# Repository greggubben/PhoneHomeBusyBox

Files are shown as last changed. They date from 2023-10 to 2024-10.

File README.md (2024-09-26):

# Phone Home Busy Box

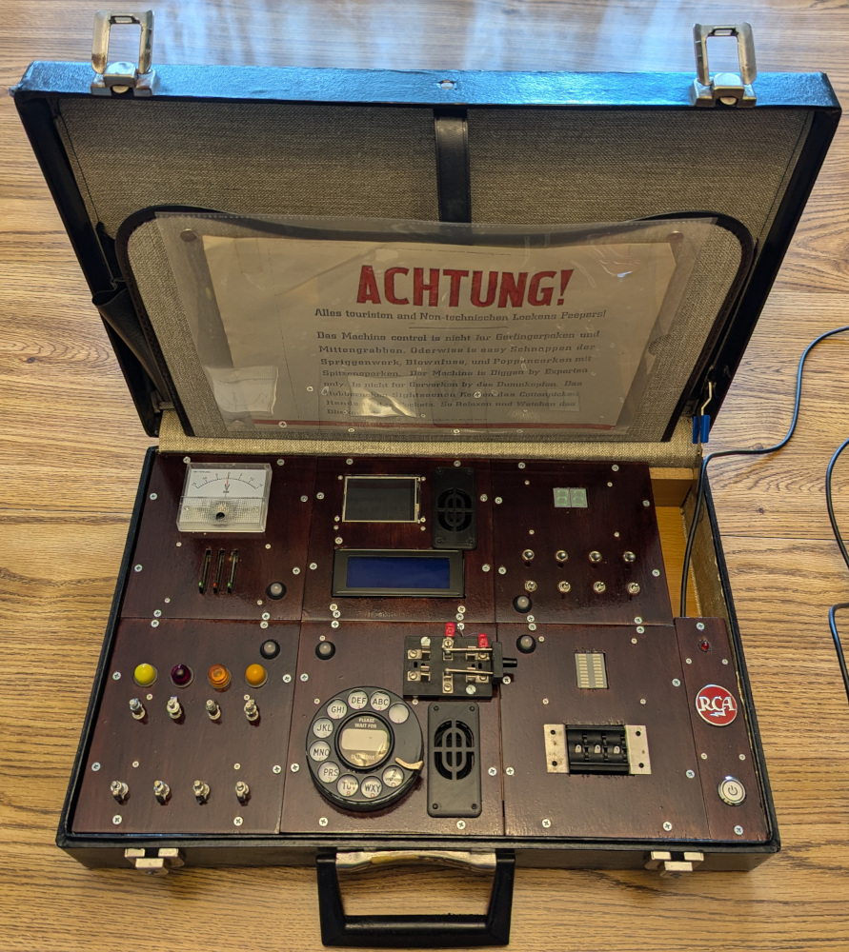
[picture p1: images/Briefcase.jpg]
Picture of the Phone Home Busy Box Briefcase


Picture of the completed Phone Home Busy Box Briefcase.

## Overview

Growing up half of my basement was an electronics lab filled with all sorts of electronic parts. My dad worked for RCA and through RCA supllied many radios to NASA, specifically the Apollo missions. When he passed, I inherited all different kinds of electronic components.

The project started, as most of my projects do, with the question:  What can I do with all these parts?  What became the Phone Home Busy Box Briefcase was inspired by a busy box my dad created for us kids. It had a group of lights and switches along with a rotary phone dialer. As you flipped switches and dialed the phone, the lights would change.

The project started as a bunch of boxes with parts.

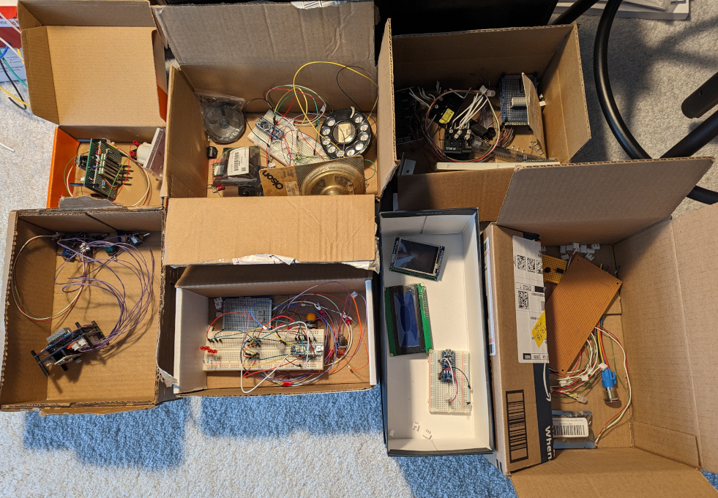
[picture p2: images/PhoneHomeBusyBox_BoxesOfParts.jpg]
Picture of the parts organized into boxes


This git repository is a collection of repositories for a Busy Box placed into a briefcase. The purpose of the Busy Box is to determine a phone number by solving 4 puzzles. This phone number must be dialed in the 5<sup>th</sup> puzzle before time runs out.

There are 6 repositories for 6 of the modules. The 7<sup>th</sup> module is the power module and does not require any code.

- [**Control Module**](Controller) handles the flow of the game.
- [**Slide into Home**](Slider) puzzle is where sliders are moved to reveal the number on the analog meter.
- [**Hook Me Up**](HookMeUp) puzzle has the player connect wires between the top(Brown) and bottom(White) terminals to turn lights on if off or off if on revealing a binary number that must be converted to a base ten number.
- [**Flip the Bits**](FlipBits) puzzle uses switches to reveal a hexidecimal number that must be converted to a base ten number.
- [**Spin Digit**](SpinDigit) puzzle has the player make all the bars go out by spinning the number wheels to reveal the number.
- [**Dialer**](DialerPuzzle) puzzle is where the number must be dialed correctly in order to phone home.

Supporting
- [**Phone Home Library**](PhoneHomeLib) is the common code and definitions used by all modules.
- [**Power Module**](Power) delivers the power to all the modules and creates the PJON data bus for all the modules to communnicate.

## Layout

The Phone Home Busy Box Briefcase layout looks like this:

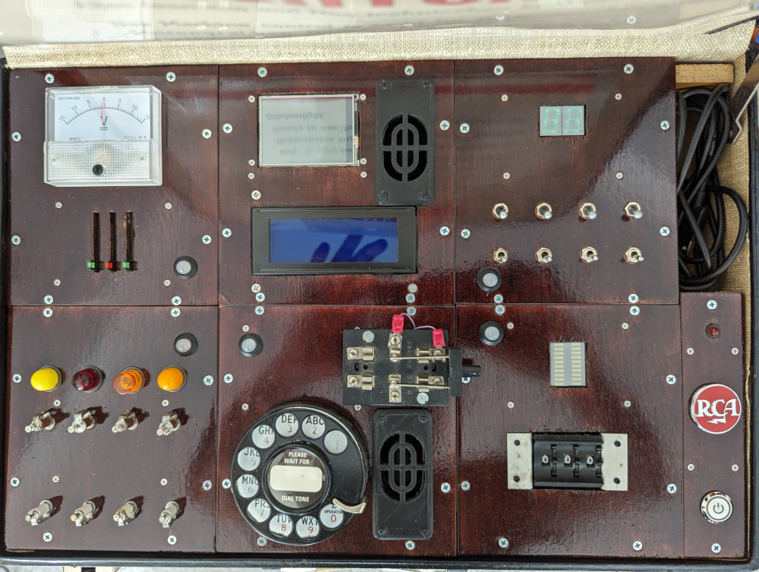
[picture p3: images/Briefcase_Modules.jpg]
Picture of the Phone Home Busy Box Briefcase with all the Modules installed


| Col<br>\\<br>Row | 1 | 2 | 3 | |
| :---: | :---: | :---: | :---: | :---: |
| 1 | **Slide into Home** | **Control Module** | **Flip the Bits** | Cable |
| 2 | **Hook me Up** | **Dialer** | **Spin Digit** | Power |

## Architecture

Each module uses a single Arduino Nano to handle its part of the puzzle. Each of the 5 puzzle modules are capable of running individually with commands being sent through the USB Serial Monitor. When playing the full game, the **Control Module** sends the same commands to each of the puzzle modules in order.

Communication happens using the [PJON \(Padded Jitterning Operative Network\)](https://github.com/gioblu/PJON) protocol over a single wire using [SoftwareBitBang](https://github.com/gioblu/PJON/tree/master/src/strategies/SoftwareBitBang). A common library, [PhoneHomeLib](PhoneHomeLib), is used to establish a common communication language between the **Control Module** and the puzzle modules.
For more details on the common architecture see the [Readme](PhoneHomeLib) in the [PhoneHomeLib](PhoneHomeLib).

## Game Play

When the briefcase is powered up, the **Control Module** pings each puzzle module to confirm it is present. Each puzzle confirms it is functioning and lets the **Control Module** know it is ready to play. The **Control Module** will then ask the player to select the level of difficulty. The TFT Touchscreen will display choice and accept touch inputs. The 4 line LCD screen will display instructions. While the game is being played the Touchscreen will display a clock be displayed showing the time remaining.

| Difficulty | Phone<br>Number | Puzzles | Behavior |
| :---: | --- | --- | --- |
| Easy | Only one | Played in Order | Used to learn the game.<br>Puzzles reveal the phone number to dial. |
| Medium | Selected from several<br>at Random | Played in<br>Random Order | Puzzles reveal the phone number to dial. |
| Hard | Selected from several<br>at Random<br>Number is in<br>Random Order | Played in<br>Random Order | Puzzles reveals random numbers<br>which must be put in the correct order<br>for the phone number to dial. |

The **Control Module** will select a phone number based on the difficulty selected. In the case of a Hard difficulty the numbers will also be randomized. Then the **Control Module** will request playing the 4 number determining puzzles (**Slide into Home**, **Hook me Up**, **Flip the Bits**, **Spin Digit**) in sequential or random order based on the difficulty. Once the 4 puzzles are solved, the **Control Module** will request playing the **Dialer** puzzle for the player to dial the correct phone number based on the results of the solved puzzles.

Colors on the puzzle indicate the state of the puzzle:

| Status<br>Color<br>LED | State | Meaning |
| :---: | :---: | --- |
| Purple | Startup | The puzzle has been powered up and is waiting for a Wakeup message. |
| Blue | Ready | The puzzle is awake and waiting for its turn to start playing. |
| Red | Initialize | The puzzle needs the Player's help initialize the puzzle for playing. |
| Yellow | Playing | The Player is playing the puzzle. |
| Green | Done | The puzzle has been solved. |

When the **Control Module** requests a puzzle to start playing, it also sends the digits the puzzle is expected to use as the solution.

If the puzzle needs the Player to Initialize the puzzle (reset the puzzle) the status LED will turn Red and Initialization instructions will be dislayed on the Control Module's LCD screen. If the puzzle is already initialized or the Player has performed the Initialization tasks, the status LED will turn Yellow and playing instructions will be displayed on the Control Module's LCD screen.

During play the with Player will attempt to solve the puzzle using the instructions provided on the LCD screen. Meanwhile the clock on the Touchscreen will continue to count down. Once the puzzle has been solved, the clock will pause and instructions on how to interpret the number will be displayed on the Touchscreen. Once the Player has determined the number, they can press Next on the Touchscreen to continue to the next puzzle and the count down will continue.

When all 4 number determining puzzles(**Slide into Home**, **Hook me Up**, **Flip the Bits**, **Spin Digit**) have been solved, the **Control Module** will start play on the **Dialer** puzzle for the Player to dial the right phone number to call home.

Upon dialing the correct phone number the count down will stop, a message saying the Player has won, and a tune will play.

## Attribution

I would like to thank [Playful Technology](https://www.youtube.com/@PlayfulTechnology) on YouTube for [introducing me to PJON as a cross module communication tool](https://www.youtube.com/watch?v=u8giZveqlxs&list=PLogiUurtMYtSxku2Itst0msCv8MC2w14P&index=1).

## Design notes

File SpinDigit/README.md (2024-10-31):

# Spin Digit

This puzzle reveals 3 digits. 

## Overview

This puzzle uses 3 rotary switches and 2 10-segment LED Bar Graph displays. The 3 rotary switches represent each of the 3 digits. As each rotary switch is turned it changes the number of LEDs lit on the 2 10-segment LED Bar Graph display. The goal is to make all the bars disappear as in nothing is lit up on the 2 10 bar LED didplays.
When solved, the number on the 3 rotary switched is the number to use.

The 10-segment LED Bar Graph display and LM3914 are throwbacks to the 70s when CBs were all the rage. We had a slide in plate installed in the cars that would accept the CB and connect it up to power and the antenna in the trunk. My Dad's Maverik had battery issues so he created an LED bar display using a LM3914 to show battery voltage and mounted it to a spare CB mount so it could be inserted into his car. The LM3914 is one of his spares, but the 10-segment LED Bar Graph is new. I do not know where the Number Dials came from, but I suspect it was used to dial in a frequency on some device.

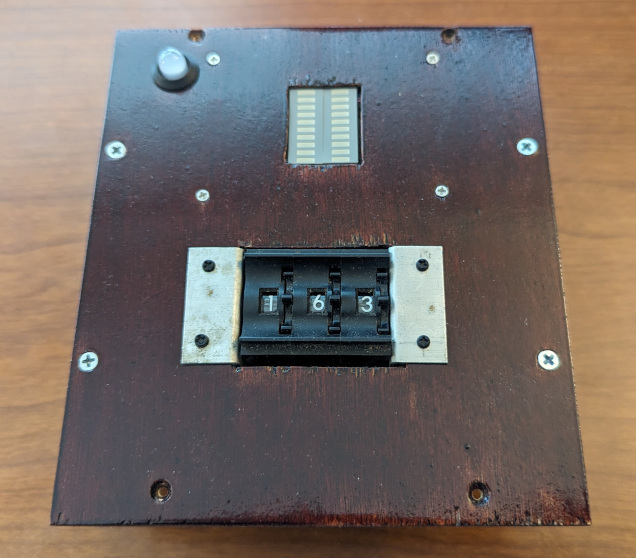
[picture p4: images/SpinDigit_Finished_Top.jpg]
Picture of finished Spin Digit module


## Hardware

The puzzle uses an Arduino Nano as the processor and 2 digital pins drive each of the LED Bar Graph displays through PWM. A MCP23O17 reads the binary value from the 3 rotary switches and is connected to the Arduino Nano via I2C.

The Arduino Nano manages the state of the puzzle which is reflected in the [8mm NeoPixel](https://www.adafruit.com/product/1734) LED from Adafruit. See the [PhoneHome_PuzzleState.h](../PhoneHomeLib/PhoneHome_PuzzleState.h) for states and colors. The [PhoneHome_Definitions.h](../PhoneHomeLib/PhoneHome_Definitions.h) file contains the standard pins used by all Arduino Nanos.

I cannot find the datasheet for the exact model of the Digitran 7-R-108 B rotary switches I used, but it is similar to one of these [Digital Display Data Sheets](https://www.digitran-switches.com/resources). The rotary switches used both binary and digital pins connectioned through the switch to a common source. I used the binary connections to decode the number dialed according to [Table 16 on the Truth Table]( https://www.digitran-switches.com/sites/digitran-switches/files/truthtables.pdf). The common is connected to ground so each of the 4 binary connected are expected to be pulled high.

The [MCP23O17](https://www.adafruit.com/product/732) is a 16 bit I/O Expander connected to the Arduino Nano using I2C. GPA0-GPA3 is connected to the right switch, GPA4-GPA7 is connected to the middle switch, and GPB0-GPB3 is connected to the left switch. This allows a full 16-bit read to return the complete value of the rotary switches. All 16 pins are initialized to use the builtin pull-up resistor. The I2C connection to the MCP23O17's SCK(12) and SDA(13) is made using the default I2C pins on the Arduino Nano. Pins A0(15), A1(16), and A2(17) on the MCP23O17 are connected to ground to use the default I2C address of 0x20. The RESET(18) pin on the MCP23O17 is connected to +5v. I had left these 4 pins floating with wildly unpredictable results. :-)

The [LM3914 Bar Display Driver](https://www.ti.com/lit/ds/symlink/lm3914.pdf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) is used to drive a [10-Segment LED Bar Graph Display](https://www.amazon.com/dp/B07BJ8ZGP7). Pins 1 , 18, 17, 16 & 15(aka LED No 1-5) of the LM3914 are connected to the Green LEDs, pins 14, 13 & 12(aka LED No 6-8) are connected to the Yellow LEDs, and pins 11 & 10(aka LED No 9-10) are connected the end LEDs.
On the LM3914, a 1.1K ohm resistor is placed between pin 8 (Ref Adj) and Ground. A 2.4K Ohm resistor is placed between pin 8 (Ref Adj) and pins 6 & 7 (RHI & Ref Out) since pins 6 & 7 are connected. Pin 9 on the LM3914 sets the Mode of the display and is connected to +5V indicating Bar Graph Mode. Pin 4 (RLO) is connected to Ground.
When I connected the Arduino pin 5 & 6 to pin 5 (Signal Source) on the LM3914, the display flashed with the PWM. I had to add a Low Pass Filter using a 4.7uF Capacitor and a 12K ohm resistor so that the PWM pulses would be leveled out for the LM3914. It turns out the LM3914 is very responsive so without the Low Pass Filter the LED Bar Graph was flashing all on to all off.

The following is a Fritzing diagram of the connections.

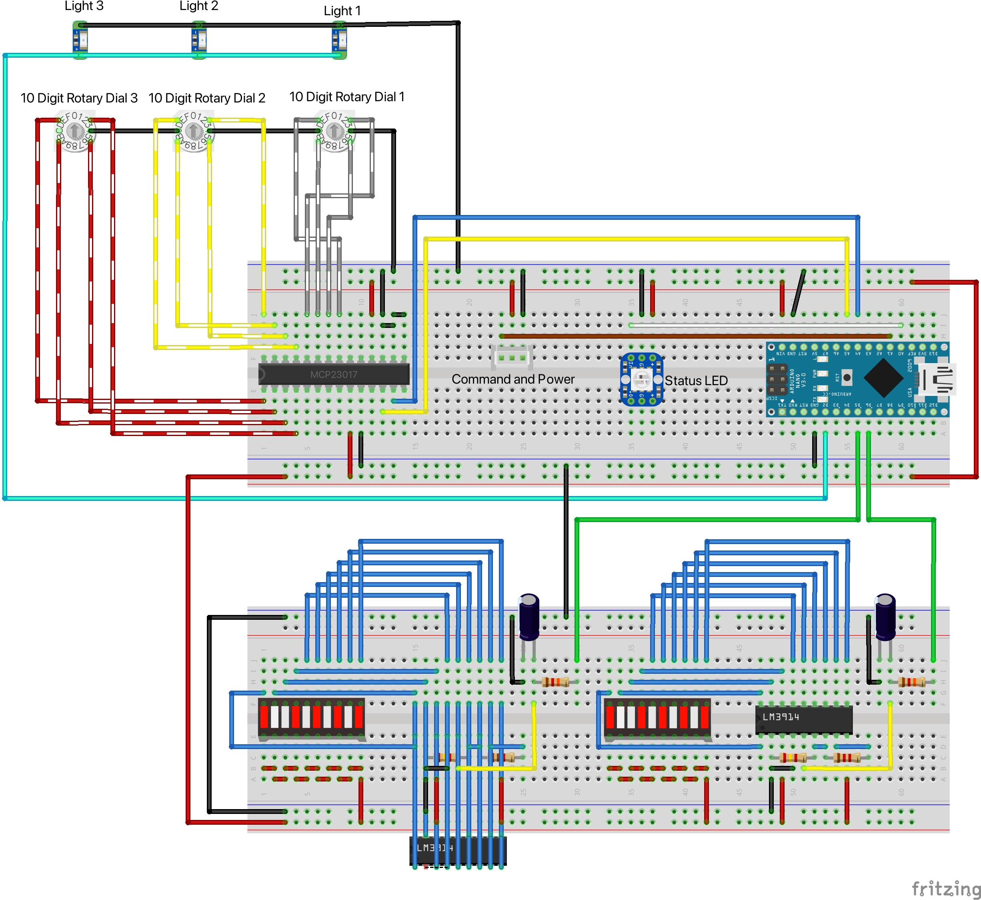
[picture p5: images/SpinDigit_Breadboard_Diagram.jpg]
Breadboard Diagram


I only wired up one of the LM3914 and LED Bar Graphs pairs on the breadboard.

The Spin Digit puzzle is soldered on 2 5cmx7cm 2.54mm double sided prototype PCB circuit board sandwiched together using headers to pass data. The Arduino Nano is placed on one of the boards using headers. The connection to the bus is made at the top of the Arduino Nano using a 3 pin JST connector. The neopixel state indicator LED is connected using a 3 pin JST connector as well. The 8 switches are connected to this board using 2 pin JST connectors.

The MCP23O17 is soldered to the same board as the Arduino using sockets. There are 3 4-pin JST connectors are attached to the IO pins on the MCP23017 as well. These are color coded to ensure the correct rotary dial is connected to the right bank of IO pins.

The LM3914s and LED Bar Graph Displays are placed on sockets soldered onto a second prototype PCB circuit boardi. Headers connect the 2 boards to pass +5v, Ground, and the 2 PWM signal lines for each display. The Low Pass Filters for each side are also soldered onto this board.

Soldered Spin Digit from the top<br>
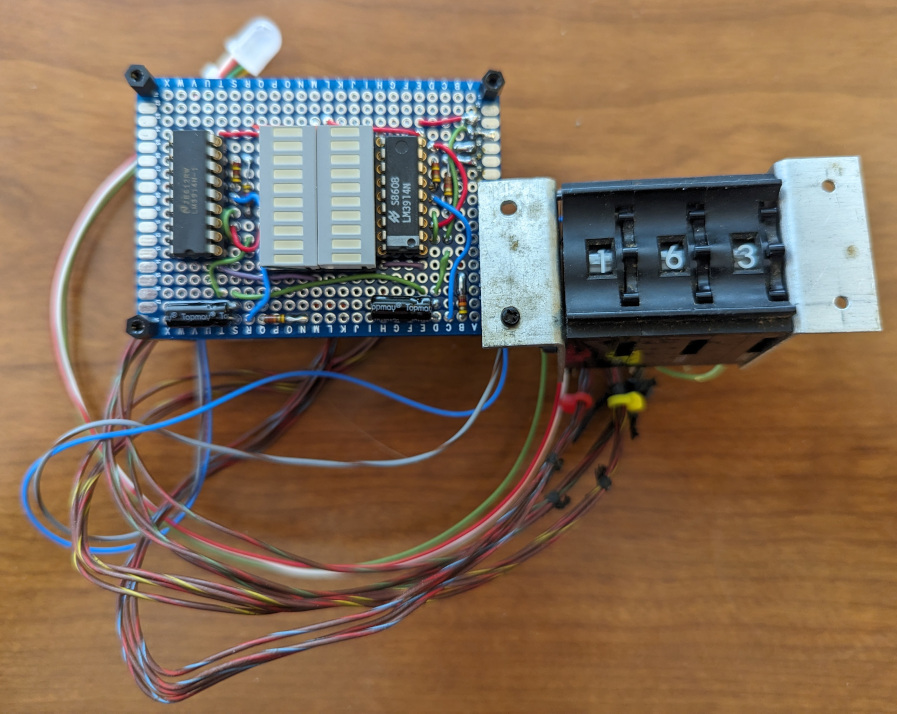
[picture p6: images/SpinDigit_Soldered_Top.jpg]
Picture of soldered Spin Digit Top


Soldered Spin Digit from the bottom<br>
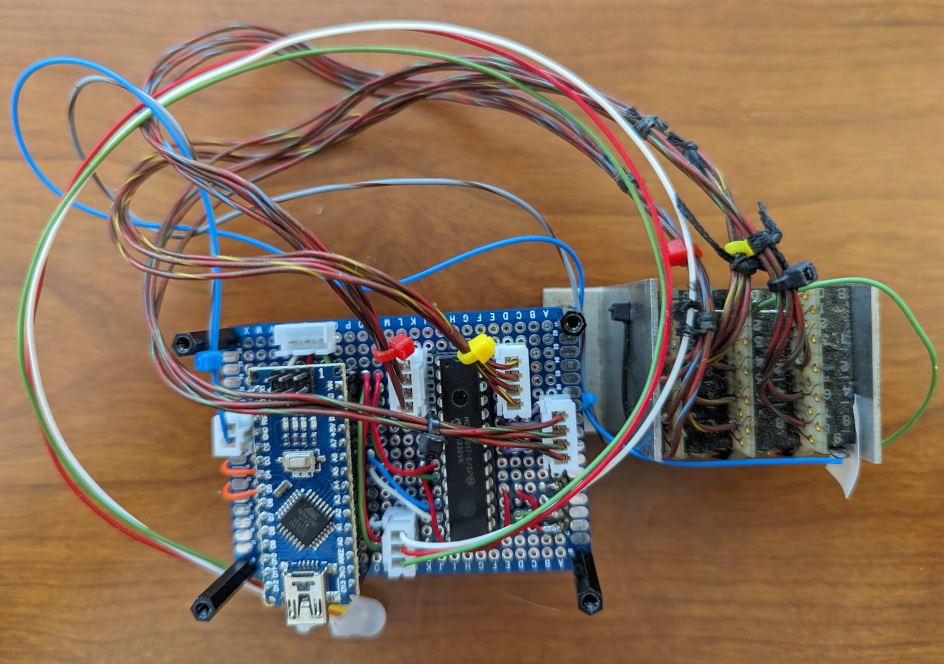
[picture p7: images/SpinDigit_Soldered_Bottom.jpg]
Picture of soldered Spin Digit Bottom


## Software

The Arduino Nano manages the [State](../PhoneHomeLib/README.md#state-diagram) of the puzzle and communicates following the [Flow between Control Module and Slide into Home module](../PhoneHomeLib/README.md#sequence-diagram).

In addition to the libaries in [PhoneHomeLib](../PhoneHomeLib), the Flip the Bits puzzle makes use of the [Bounce2](https://github.com/thomasfredericks/Bounce2) library from Thomas Fredericks and the [Adafruit-MCP23O17-Arduino-Library](https://github.com/adafruit/Adafruit-MCP23017-Arduino-Library) library from Adafruit.

The rotary switches are arranged as a row of 3. The Adafruit library is used for the Arduino Nano to communicate with the MCP23O17. Both A and B banks are read from at the same time as a full word (2 bytes) and the high nibble (4 bits) is masked away by anding with 0x0FFF. To read the value of the 3 rotary switches a combination of masking and shifting is used. To get the value of the first(right) rotary switch the input is masked(anded) with 0x00F which leaved the low 4 bits. The second(middle) rotary switch is masked (anded) with 0x0F0 and then shifted by 4 bits to place the value in the low 4 bits. The third(left) rotary switch is masked (anded) with 0xF00 and then shifted by 8 bits to place the value in the low 4 bits.

The number on the display is calculated by summing the absolute value each read digit is away from the correspondng target number. This digitsAway number is the number of LEDs that should be lit on the Bar Graphs. The right 10-segment LED Bar Graph display is for Odd numbers and is connected to pin 5. The left LED Bar Graph represents Even numbers and is connected to pin 6. The value for the Even number (left) display is determined by dividing the digitsAway number by 2. The value for the Odd number (right) display is determined by adding the modulo of digitsAway by 2 plus the Even number.

During Wake the puzzle will turn on all the LED segments in both 10-segment LED Bar Graph displays and then turn them back off. The rotary switches also have a light and those are turn on and then off as well.

During Initialize the puzzle checks that all the rotary switches are set to 0. The difficulty is handled by the controller so nothing unique is performed by the puzzle. The light for the rotary switches is turned on as well.

During Play, the rotary switches are read, the digitsAway is calculated, and its value is displayed as lit LED Bars. If the number is 20 or over all the LEDs are lit up. The light for the rotary switches is turned on as well.
When the target number is discovered, all play stops and the puzzle is considered solved. When solved, the light for the rotary switches is turned off.

When the puzzle is solved the rotary switches stop being read and the value on the switches is the target number.

## Assembly

A piece of scrap 1/4 inch MDF was used to test the layout and fit all the parts. Once the layout for the puzzle was complete the puzzle was test fitted into the briefcase for testing with the other puzzles and control module. The MDF prototype was used as a template for the final 1/4 inch birch plywood. The final plywood was stained and clear coated.  Sides were added so the puzzle could be pulled out of the briefcase and set on the desk when connected directly to the computer for development. In addition wiring clips were added to the sides to keep the wires tidy.

Top view of the prototype Spin Digit showing the placement of all the components.<br>
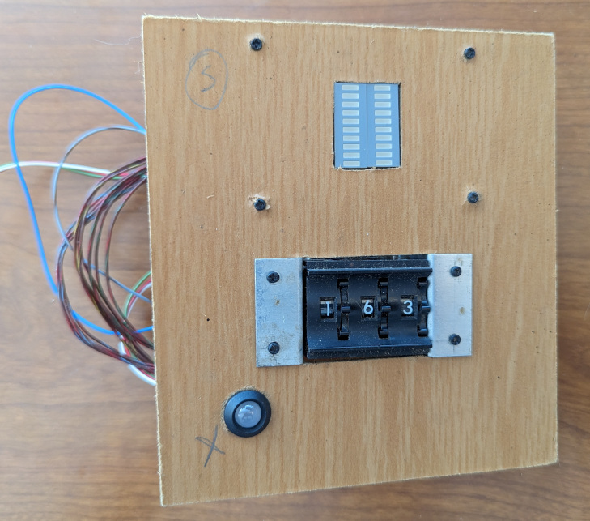
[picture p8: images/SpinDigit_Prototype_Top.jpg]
Picture of prototype Spin Digit module


Bottom view of the finished Spin Digit showing the wire organization.<br>
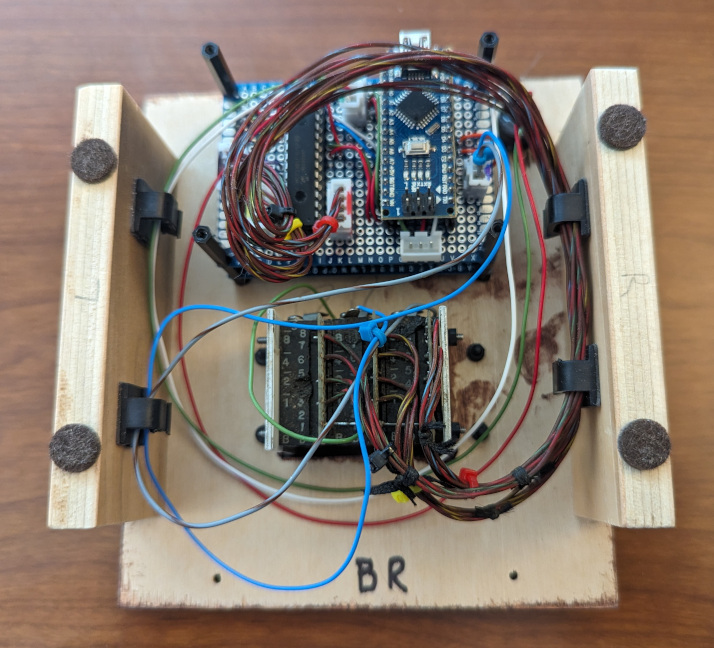
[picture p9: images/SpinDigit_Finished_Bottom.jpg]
Picture of finished Spin Digit module


The wire connectors for the rotary switches are labeled in color indicating which switch connector should be attached where.

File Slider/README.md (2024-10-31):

# Slide into Home

Number revealing puzzle

## Overview

This puzzle uses 3 Sliders to adjust the value on a voltmeter. The sliders will adjust where the needle is pointing on the voltmeter. Each slider is capable of changing the voltmeter between 0(bottom) and 9(top) places. Starting with the left slider, when the number is discovered the led will light up. However the puzzle is not solved until all sliders are moved from the bottom. Using the 2 leftmost sliders, the 2 leds will light up when the number is discovered. It is possible to have all 3 leds lit up, but the puzzle is not solved because the sliders must be further apart. When solved, the vaule pointed to by the needle on the voltmeter is the number to use.

The voltmeter is a new component because all the meters we had in the basement when growing up have been incorporated into other projects. The slider pots with LEDs I had aquired a while ago and could not figure out what to do with them until this project came along. The LEDs on the sliders provide interesting feedback.

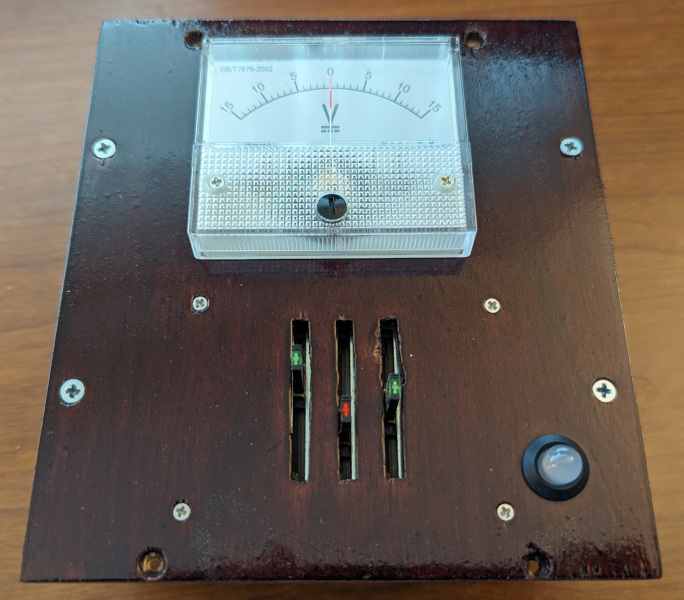
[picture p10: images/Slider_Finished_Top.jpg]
Picture of finished Slide into Home module


## Hardware

The puzzle uses an Arduino Nano as the processor, 3 Sliders as inputs, and a Voltmeter as the display.

The Arduino Nano manages the state of the puzzle which is reflected in the [8mm NeoPixel](https://www.adafruit.com/product/1734) LED from Adafruit. See the [PhoneHome_PuzzleState.h](../PhoneHomeLib/PhoneHome_PuzzleState.h) for states and colors. The [PhoneHome_Definitions.h](../PhoneHomeLib/PhoneHome_Definitions.h) file contains the standard pins used by all Arduino Nanos. The Arduino Nano takes the input from the Sliders and moves the needle on the voltmeter to display the value.

The sliders are Alpha [RA3045F-20G-15LC-B10K](https://www.mouser.com/ProductDetail/Alpha-Taiwan/RA3045F-20G-15LC-B10K-C?qs=8YYpzd7qSxKwnrbI1rOsAQ%3D%3D) (30mm travel, linear 10K, Green LED) and [RA3045F-20R-15LC-B10K](https://www.mouser.com/ProductDetail/Alpha-Taiwan/RA3045F-20R-15LC-B10K-C?qs=8YYpzd7qSxLlrphi%252BudaCA%3D%3D) (30mm travel, linear 10K, Red LED) from are wired to have 0 as the bottom and 9 at the top. They are arranged in Green, Red, Green LED order. The LEDs have a resister in series. The potentiometers are wire to pins A4, A3, and A2 using AREF to supply power. The corresponding LEDs are wired to pins 4, 3, and 2.

The display uses a [+/- 15V DC Analog Panel Meter](https://www.adafruit.com/product/4403) from Adafruit. The internal resister was removed so the Arduino Nano could drive the meter using PWM. The meter is wired to pins 9 and 10 so the voltage can be reversed to show negative numbers. Pin 9 is connected to the Plus terminal on the voltmeter and pin 10 is connected to the Negative terminal.

The following is a Fritzing diagram of the connections.

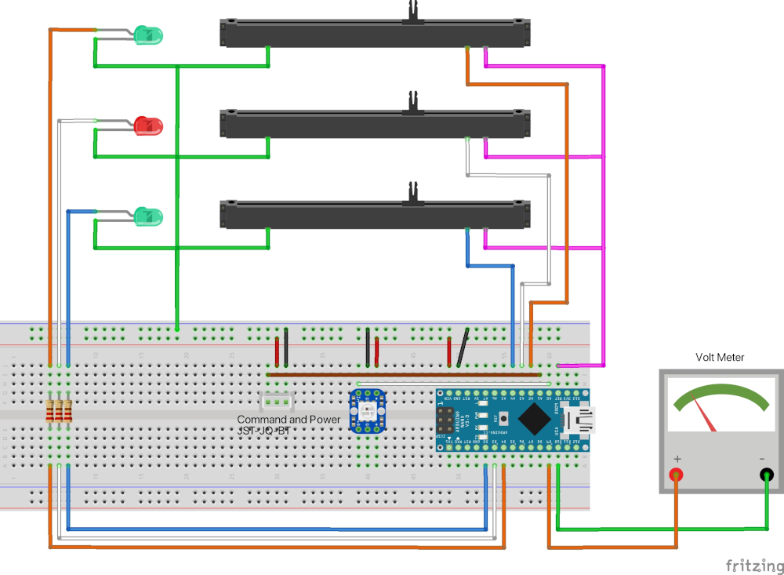
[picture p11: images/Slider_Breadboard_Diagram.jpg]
Breadboard Diagram


The following photo shows the puzzle initially created on the breadboard. The sliding potentiometers were having difficulty staying put in the breadboard so I had to solder them onto a perfboard to complete my testing.

Breadboard picture of Slide into Home

The Side into Home is soldered on to 2 boards sandwiched together and connected using 2 sets of headers. One set of headers is for reading the slider potentiometer values and the other is for controlling the corresponding LEDs on the sliders.
The Arduino Nano is soldered on to a single 5cmx7cm 2.54mm double sided prototype PCB circuit board using headers. The connection to the bus is made at the top of the Arduino Nano using a 3 pin JST connector. The neopixel state indicator LED is connected using a 3 pin JST connector as well. A 2 pin JST connector is used to connect the voltmeter.
The slider potentiometers are soldered to a fiberglass perf board cut to the same size at the PCB prototype board used for the Arduino Nano.

Top view of Soldered Slider<br>
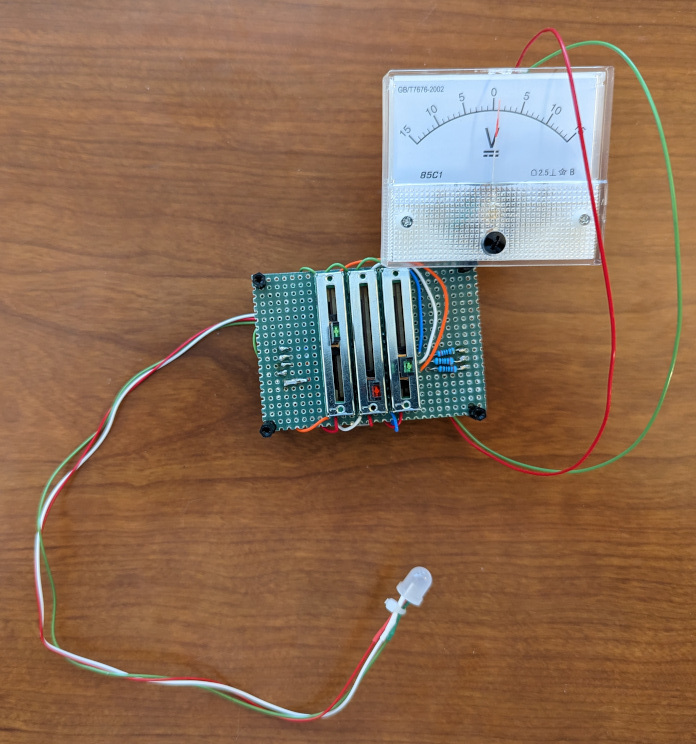
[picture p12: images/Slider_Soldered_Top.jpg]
Picture of soldered Slide into Home


Side view of Soldered Slider<br>
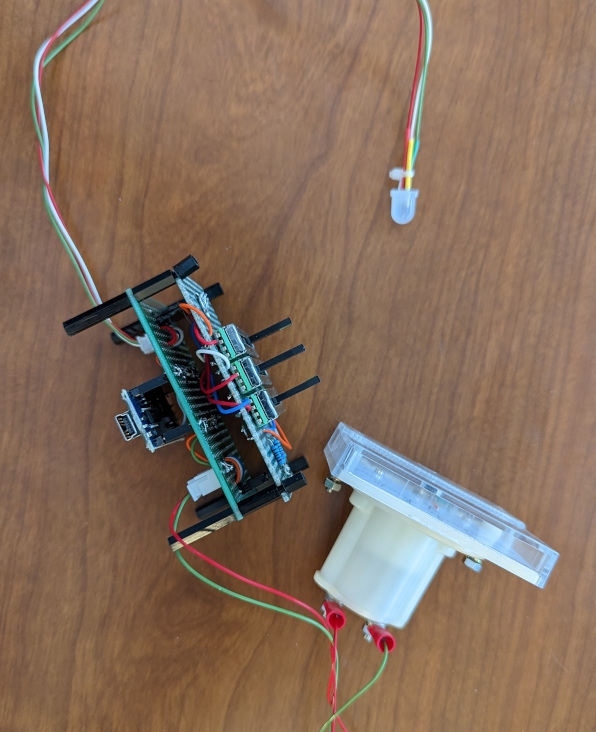
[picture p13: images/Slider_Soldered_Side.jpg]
Picture of soldered Slide into Home


Bottom view of Soldered Slider<br>
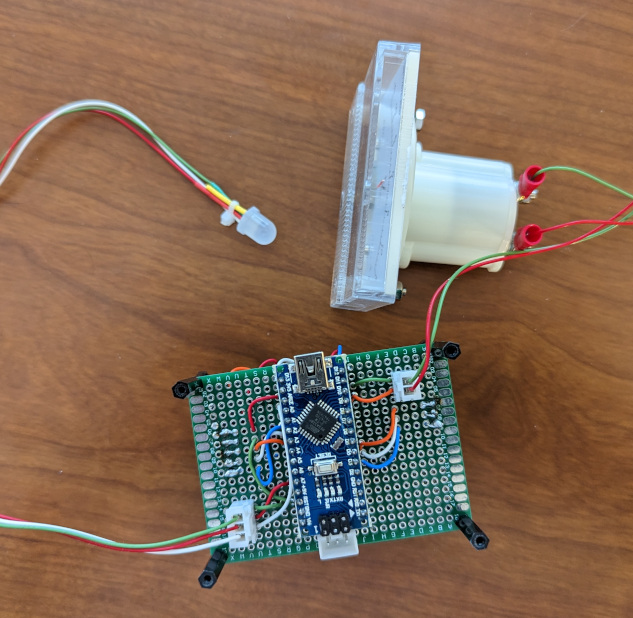
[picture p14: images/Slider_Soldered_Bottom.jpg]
Picture of soldered Slide into Home


## Software

The Arduino Nano manages the [State](../PhoneHomeLib/README.md#state-diagram) of the puzzle and communicates following the [Flow between Control Module and Slide into Home module](../PhoneHomeLib/README.md#sequence-diagram).

The sliders are configured to have 0 as the bottom and 9 at the top. They are arranged in Green, Red, Green LED order. On each Loop the values of the sliders are read and a resulting number is generated. This resulting number is then displayed on the voltmeter as either a positive or negative number limited to +/- 15.

During Wake the puzzle pings the voltmeter from -15 to +15. The positive is created by setting Negative Pin 10 to LOW and Plus Pin 9 to HIGH. The negative number is created by setting the Plus Pin 9 to LOW and the Negative Pin 10 to HIGH. The LEDs on the Sliders are also flashed.

During Initialize the puzzle will show the values of the sliders to help the player get to zero. Initialization functions similar to Play, but the target number is 0.

During Play, the slider values are read on each loop. A number is calculated and then displayed on the voltmeter. A PWM value is looked up in a array of values using the calculated number as the index. If the calculated number is positive, the Negative Pin 10 is set to LOW and the Plus Pin 9 is set to the PWM value using analogWrite. If the calculated number is negative, the Plus Pin 9 is set to LOW and the Negative Pin 10 is set to the PWM value using analogWrite.
Another feature of the puzzle is the use of the LEDs on the sliders. If the leftmost slider finds the target number, it's LED will light up. However, the puzzle is not solved until all the sliders are moved from 0 or the bottom. Using the 2 left sliders, both their LEDs will light up if combined they find the target number. All 3 LEDs light up when all 3 sliders are moved to find the target number.

When the puzzle is solved the sliders stop being read and the voltmeter is left on the target number.

## Assembly

A piece of scrap 1/4 inch MDF was used to test the layout and fit all the parts. Once the layout for the puzzle was complete the puzzle was test fitted into the briefcase for testing with the other puzzles and control module. The MDF prototype was used as a template for the final 1/4 inch birch plywood. The final plywood was stained and clear coated.  Sides were added so the puzzle could be pulled out of the briefcase and set on the desk when connected directly to the computer for development. In addition wiring clips were added to the sides to keep the wires tidy.

Top view of the prototype Slider showing the placement of all the components.<br>
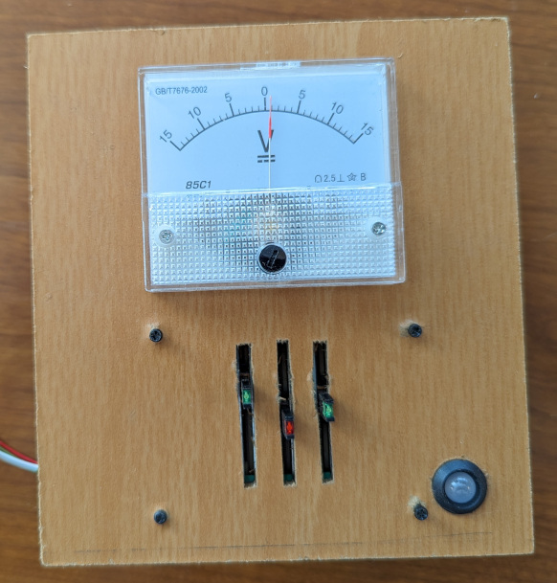
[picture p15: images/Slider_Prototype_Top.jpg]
Picture of prototype Slide into Home


Bottom view of the finished Slider showing the wire organization.<br>
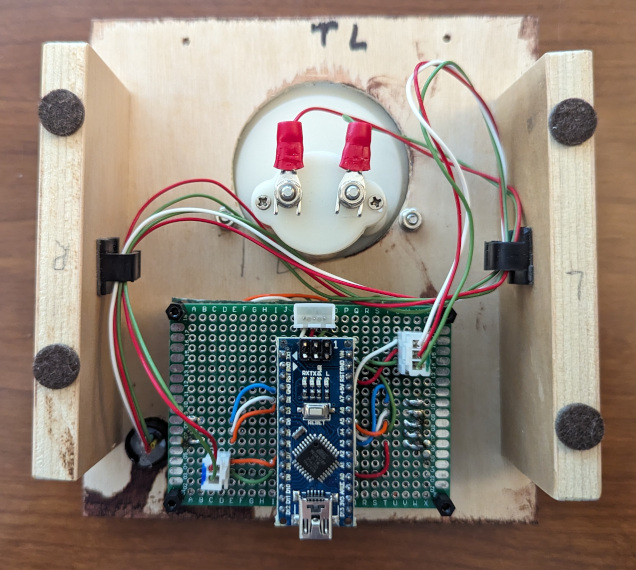
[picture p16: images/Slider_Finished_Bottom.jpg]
Picture of finished Slide into Home module


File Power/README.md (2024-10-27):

# Power Module

This module delivers power to the entire briefcase.

## Overview

The power module uses a bus to deliver +5V to all the other modules. The Blinking LED is referenced by the [Achtung!](https://en.wikipedia.org/wiki/Blinkenlights) sign my Dad brought home from work in the late 70s. My Dad worked for RCA and I found an RCA badge so I put it on the Power module. The briefcase is the same one that was used to hold the Datac 1000 and course material for the microprocessor training course by Dad took in the late 70s.

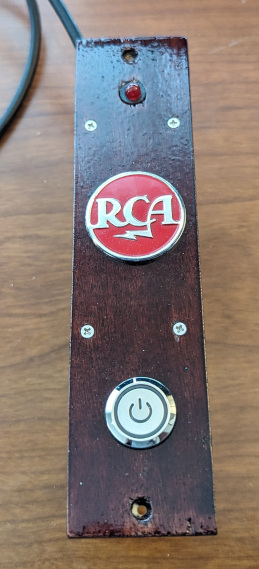
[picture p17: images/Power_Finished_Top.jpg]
Picture of finished Power module


## Hardware

The power module uses a push button switch to turn the power on and off. The push button also has an LED which lights up when power is on.

There is no Arduino Nano required.

A 555 Timer IC is used to create the blinking LED. The blinking light is for the people who read the sign.

The following is a Fritzing diagram of the connections.

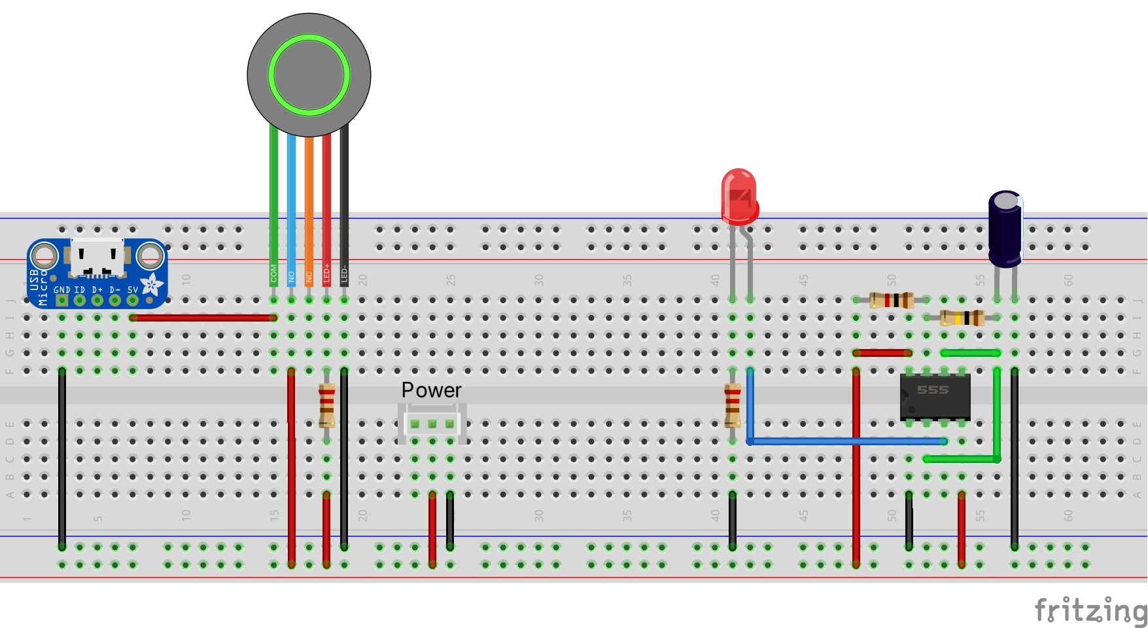
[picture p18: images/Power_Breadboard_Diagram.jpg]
Breadboard Diagram


The 555 is soldered using a socket on one 3cmx7cm 2.54mm double sided prototype PCB circuit board. The connection to the bus is made using a 3-pin JST connector with only the +5v and Ground connected. There is no need to connect the data line.

A 5-pin JST is used to connect the push button power switch. 3 of the wires are for the switch of which only the common and NO are used. The other 2 wires are used to light the LED when the briefcase is powered on.
The LED is connected with a 2-pin JST.

## Assembly

A piece of scrap 1/4 inch MDF was used to test the layout and fit all the parts. Once the layout for the puzzle was complete the puzzle was test fitted into the briefcase for testing with the other puzzles and control module. The MDF prototype was used as a template for the final 1/4 inch birch plywood. The final plywood was stained and clear coated.

A RCA badge is added as a nod to where my Dad worked for most of his life.

A bus is created for the distribution of +5V, PJON Data, and Ground using 3-pin JST connectors. The +5V is the center pin. Ground and PJON Data are on the outside. This way if there is an accident trying to plug it in backwards,the +5V will not be sent to places it does not belong.

Empty Briefcase showing the wiring bus and wire bundles for connecting to each of the modules.
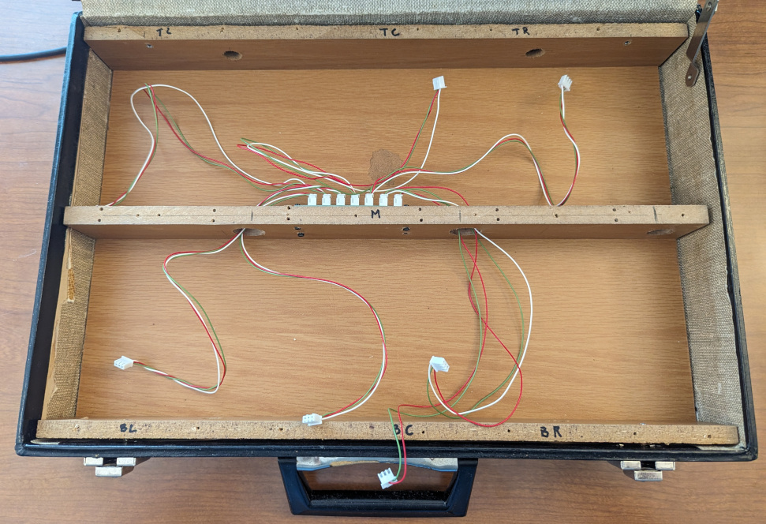
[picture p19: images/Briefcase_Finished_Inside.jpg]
Picture of inside of Briefcase


Bottom view of the finished Power Module.<br>
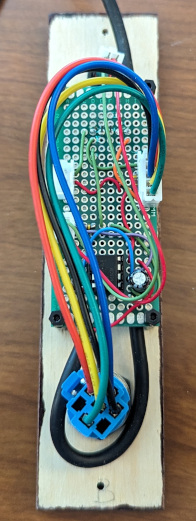
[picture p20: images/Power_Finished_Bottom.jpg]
Picture of finished Power module


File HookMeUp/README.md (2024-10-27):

# Hook Me Up

This puzzle reveals 1 digit. While technically 4 bits can go to 2 digits, the range is limited to 16 and therefore not suitable for revealing a full 2 digit number.

## Overview

This puzzle uses 8 standoffs in 2 rows of 4 and 1 row of 4 lights. Clipleads are connected from the bottom row to the top row. If the connection is correct a light will either turn off if it was initially on or turn on if it was initially off. The puzzle is solved when each of the 4 lights remain changed from on to off or off to on. When solved, the lights reveal the binary representation of the number to use. A [Hexidaisy Hexidecimal Calculator](https://www.computerhistory.org/collections/catalog/102757130) is provided to convert the binary to decimal using the binary to hexidecimal table on the front. (the number is only between 0 and 9)

The 4 lights are a nod to the "Busy Box" my Dad made for us kids that would blink and change when a number was dialed by the rotary dial. We used clip leads all the time while prototyping projects in the basement. I found the terminal posts in a parts bin organizer my Dad had.

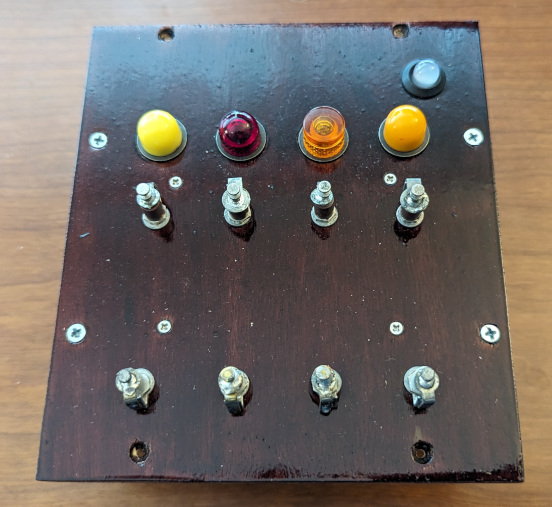
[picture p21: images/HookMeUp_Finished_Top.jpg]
Picture of finished Hook Me Up module


## Hardware

The puzzle uses an Arduino Nano as the processor, 4 digital pins as drivers(outputs), 4 digital pins as receivers(inputs), and 4 digital pins for the lights.

The Arduino Nano manages the state of the puzzle which is reflected in the [8mm NeoPixel](https://www.adafruit.com/product/1734) LED from Adafruit. See the [PhoneHome_PuzzleState.h](../PhoneHomeLib/PhoneHome_PuzzleState.h) for states and colors. The [PhoneHome_Definitions.h](../PhoneHomeLib/PhoneHome_Definitions.h) file contains the standard pins used by all Arduino Nanos. The Arduino Nano takes the input from the Sliders and moves the needle on the voltmeter to display the value.

The standoffs are simple insulated posts. A bracket was soldered between the post and base nut of the standoff so there is connectivity to the bottom screw. This allows the wire connecter to remain under the board. The standoffs closest to the lights are brown and the other set is white, but otherwise they are the same. The brown set are Drivers and are wired up to pins 2, 3, 4, and 5. The white set are Receivers and are wired up to pins 6, 7, 8, and 9.

The lights are wired up to A2, A3, A4, and A5.

The following is a Fritzing diagram of the connections.

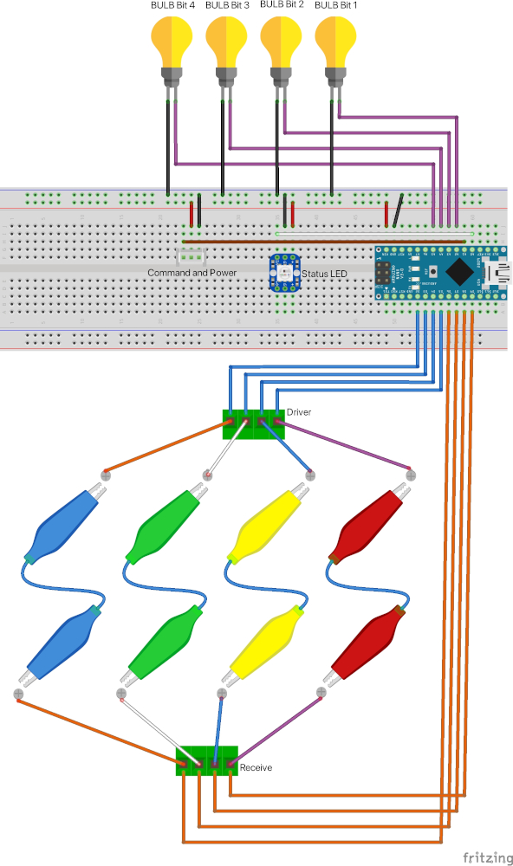
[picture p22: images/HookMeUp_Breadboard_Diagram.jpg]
Breadboard Diagram


The following photo shows the puzzle initially created on the breadboard. Breadboard jumper wires were used instead of clipleads and LEDs were used instead of the lights.

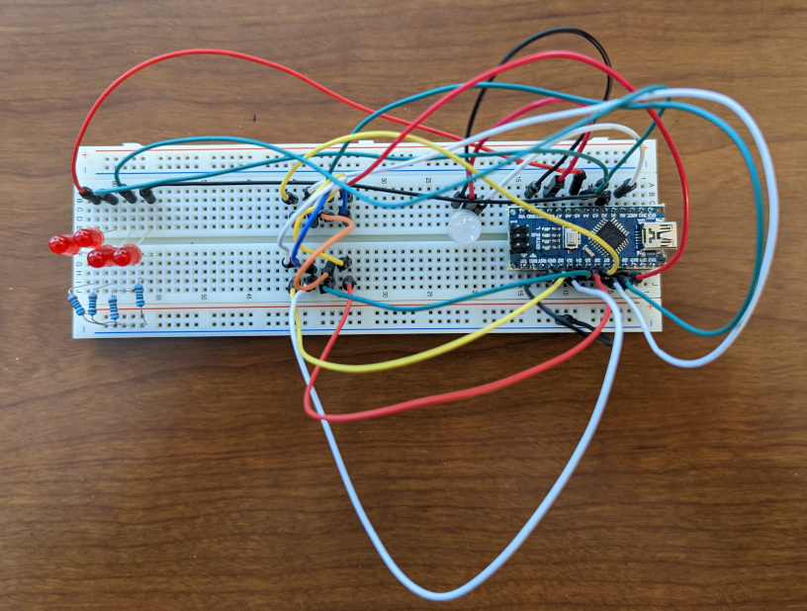
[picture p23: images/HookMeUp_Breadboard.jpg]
Breadboard picture of Hook Me Up


The Hook Me Up puzzle is soldered on to a single 5cmx7cm 2.54mm double sided prototype PCB circuit board. The Arduino Nano is placed on headers. The connection to the bus is made at the top of the Arduino Nano using a 3 pin JST connector. The neopixel state indicator LED is connected using a 3 pin JST connector as well. The wires to the standoffs are color coded and attached to screwdown terminal blocks. The lights are connected using 2 pin JST connectors.

Soldered Hook Me Up<br>
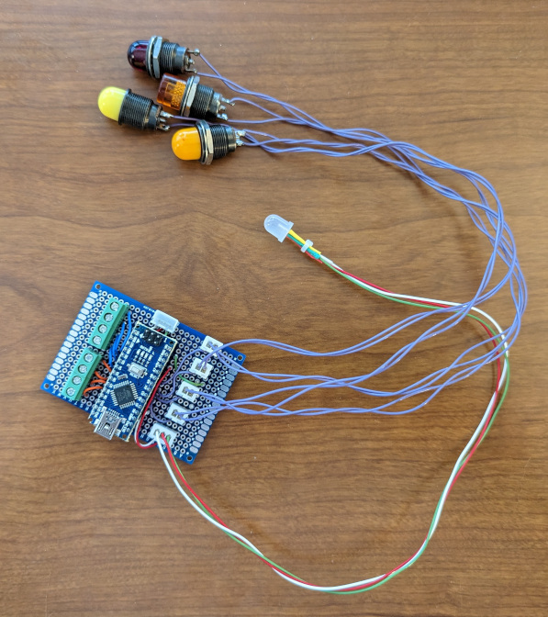
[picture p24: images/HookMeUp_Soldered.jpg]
Picture of soldered Hook Me Up


## Software

The Arduino Nano manages the [State](../PhoneHomeLib/README.md#state-diagram) of the puzzle and communicates following the [Flow between Control Module and Slide into Home module](../PhoneHomeLib/README.md#sequence-diagram).

The standoffs for connecting the clipleads are arranged in 2 groups of 4. One set of 4 are attached to the brown standoffs and are the Driver pins. The other set of 4 are attached to the white standoffs and are the Receiver pins. One at a time each Driver pin is set to HIGH while the remaining 3 are set to LOW. While one of the Driver pins is HIGH, the 4 Receiver pins are read to see which Driver/Receiver set is connected.

During Wake the puzzle will turn on then off all 4 of the lights.

During Initialize the puzzle checks if there is any connection between the Driver pins and the Receiver pins. Game play will proceed when there is no connection between the Driver pins and Receiver pins. 

During Play, an inverted binary number will be displayed on the lights. The Driver pins will be matched to a light. This matched set will be random for Hard difficulty. The Receiver pins will also be paired with the Driver pins. This pairing will be random for Medium and Hard difficulty.
When a connection is made between the paired Driver and Receiver pins, the matching light is turned off if on or turned on if off. Game play continues until all 4 connections have been made causing all the lights to flip state.

When the puzzle is solved the connections stop being tested and the lights show in binary the target number. The binary to hex table on the Hexadaisy can be used to convert the number from binary to decimal since the digit is always less than 10.

## Assembly

A piece of scrap 1/4 inch MDF was used to test the layout and fit all the parts. Once the layout for the puzzle was complete the puzzle was test fitted into the briefcase for testing with the other puzzles and control module. The MDF prototype was used as a template for the final 1/4 inch birch plywood. The final plywood was stained and clear coated.  Sides were added so the puzzle could be pulled out of the briefcase and set on the desk when connected directly to the computer for development. In addition wiring clips were added to the sides to keep the wires tidy.

Top view of the prototype Hook Me Up showing the placement of all the components.<br>
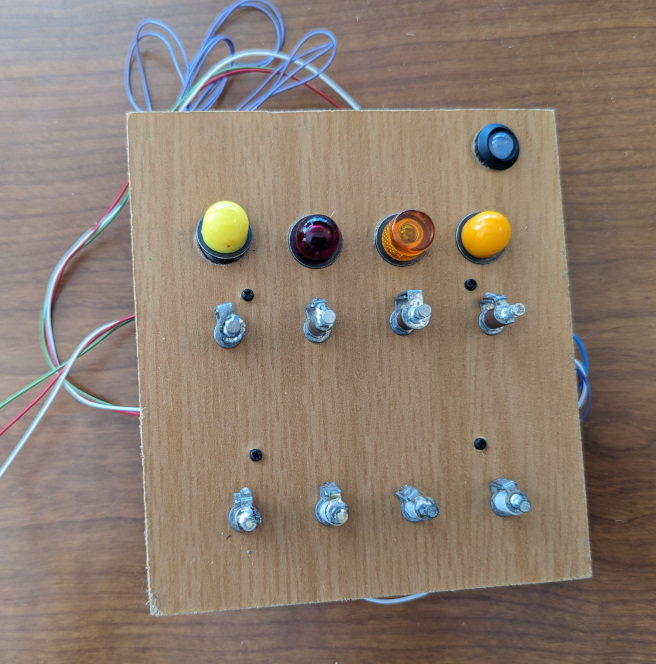
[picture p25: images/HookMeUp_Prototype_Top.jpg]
Picture of prototype Hook Me Up


Bottom view of the finished Hook Me Up showing the wire organization.<br>
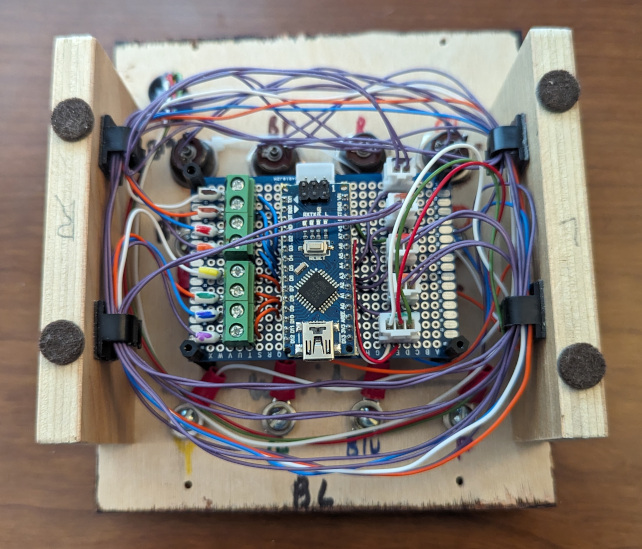
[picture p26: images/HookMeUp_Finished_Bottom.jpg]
Picture of finished Hook Me Up module


The holes for the components are labeled in color indicating which wire or light should be attached where.

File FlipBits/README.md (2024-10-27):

# Flip the Bits

This puzzle reveals 2 digits. While technically a byte (8 bits) can go to 3 digits, the range is limited to 255 and therefore not suitable for revealing a full 3 digit number.

## Overview

This puzzle uses 8 switches in 2 rows of 4 and 2 7-segment displays. The 8 switches represent each of 8 bits. As each switch is flipped it changes the value of a byte. The byte is displayed on the 2 7-segment displays. The display flashes "Hi" or "Lo" depending on whether the number displayed is higher or lower than the target number.
When solved, the display reveals the hex representation of the number to use. A [Hexidaisy Hexidecimal Calculator](https://www.computerhistory.org/collections/catalog/102757130) is provided to convert the hex to decimal using the hex to decimal conversion pairing along the edge.

The switches are from a collection of switches my Dad had in the basement. We used those switches in many projects. It seemed right they should be used here as well. The Hexidaisy came from the Microprocessor course I bought from one of my Dad's coworkers who did not think much of microprocessors.

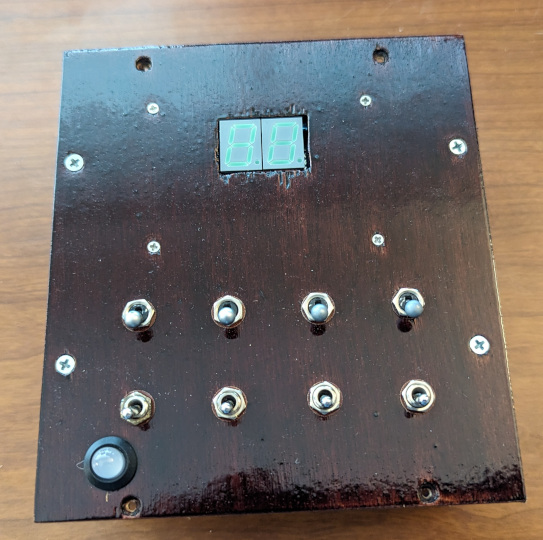
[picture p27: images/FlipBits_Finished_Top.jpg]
Picture of finished Flip the Bits module


## Hardware

The puzzle uses an Arduino Nano as the processor and 8 digital pins are connected to switches. A MCP23O17 drives the 2 7-segment displays and is connected to the Arduino Nano via I2C.

The Arduino Nano manages the state of the puzzle which is reflected in the [8mm NeoPixel](https://www.adafruit.com/product/1734) LED from Adafruit. See the [PhoneHome_PuzzleState.h](../PhoneHomeLib/PhoneHome_PuzzleState.h) for states and colors. The [PhoneHome_Definitions.h](../PhoneHomeLib/PhoneHome_Definitions.h) file contains the standard pins used by all Arduino Nanos. The Arduino Nano takes the input from the Sliders and moves the needle on the voltmeter to display the value.

The 8 switches are wired to pins 2 through 9. Pins 2 through 5 are connected to the top row from left to right and pins 6 through 9 are connected to the bottom row from left to right. The connections are color coded and ensure they are installed in the correct order. Each of the 8 switches is connected to a 2 pin JST connector. There 2 different type of switches as well to help distinguish the difference between the rows.

The [MCP23O17](https://www.adafruit.com/product/732) is a 16 bit I/O Expander connected to the Arduino Nano using I2C. Each bank of 8 bits controls a [HDSP5601](https://www.mouser.com/ProductDetail/Broadcom-Avago/HDSP-5601?qs=pQfy5%252BKCabIyrlT3Y4pBSQ%3D%3D) Green 7 segment display. The I2C connection to the MCP23O17's SCK(12) and SDA(13) is made using the default I2C pins on the Arduino Nano. Pins A0(15), A1(16), and A2(17) on the MCP23O17 are connected to ground to use the default I2C address of 0x20. The RESET(18) pin on the MCP23O17 is connected to +5v. I had left these 4 pins floating with wildly unpredictable results. :-)

```
  -a-
 |   |
 f   b
 |   |
  -g-
 |   |
 e   c
 |   |
  -d-   p
```

When connected to the 16 bit I/O Expander the byte layout is `pgfedcba` for each port as the following table shows:

| HDSP5601<BR>Display<BR>Letter | HDSP5601<BR>Display<BR>Pin | MCP23O17<BR>Bank A (GPA)<BR>Upper Nibble | MCP23O17<BR>Bank B (GPB)<BR>Lower Nibble |
| :---: | :---: | :---: | :---: |
| a | 7 | 21 | 1 |
| b | 6 | 22 | 2 |
| c | 4 | 23 | 3 |
| d | 2 | 24 | 4 |
| e | 1 | 25 | 5 |
| f | 9 | 26 | 6 |
| g | 10 | 27 | 7 |
| p | 5 | 28 | 8 |
| +5v | 3 & 8 | | |

+5v is supplied to the anode pins 3 and 8 on the 7-segment display. The MCP23O17 pins will light the segment LED when set to LOW or ground and will turn off the segment LED when set to HIGH. In other words, the pin values for the I/O pins is inverted from turning on/off the segment's LED. A 220 ohm resister is place between the MCP23O17 and each of the HDSP5601 segment LED Cathode pin.

The following is a Fritzing diagram of the connections.

Breadboard Diagram

Connecting all of switches to a breadboard and hooking up the 7-segment displays with jumper wire became a big mess, so I went right to soldering the board. I do not have a photo of the attempt to breadboard.

The Flip the Bits puzzle is soldered on 2 5cmx7cm 2.54mm double sided prototype PCB circuit board sandwiched together using headers to pass data. The Arduino Nano is placed on one of the boards using headers. The connection to the bus is made at the top of the Arduino Nano using a 3 pin JST connector. The neopixel state indicator LED is connected using a 3 pin JST connector as well. The 8 switches are connected to this board using 2 pin JST connectors.

The MCP23O17 and 2 HDSP5601s use sockets soldered to the second prototype PCB circuit board. The headers between the boards carry the I2C SDA and SCK signals from the Arduino Nano along with +5v and Ground.

Soldered Flip the Bits from the top<br>
Picture of soldered Flip the Bits Top

Soldered Flip the Bits from the bottom<br>
Picture of soldered Flip the Bits Bottom

## Software

The Arduino Nano manages the [State](../PhoneHomeLib/README.md#state-diagram) of the puzzle and communicates following the [Flow between Control Module and Slide into Home module](../PhoneHomeLib/README.md#sequence-diagram).

In addition to the libaries in [PhoneHomeLib](../PhoneHomeLib), the Flip the Bits puzzle makes use of the [Bounce2](https://github.com/thomasfredericks/Bounce2) library from Thomas Fredericks and the [Adafruit-MCP23O17-Arduino-Library](https://github.com/adafruit/Adafruit-MCP23017-Arduino-Library) library from Adafruit.

The switches are arranged in 2 groups of 4. The Arduino Nano pins (2-9) attached to the switches have the pull-up resister enabled. When the switch is thrown, the pin is grounded causing the change. The library Bounce2 is used to handle debouncing the switch. Each of the 8 pins is attached to an array of 8 Bounce2 objects which in turn is read from High(2^7) bit to Low(2^0) bit to produce a full byte.
The Adafruit library is used for the Arduino Nano to communicate with the MCP23O17. Both A and B banks are written to at the same time. The byte generated from reading the switches is broken into upper nibble and lower nibble. The nibble is looked up in an array which contains the binary representation of the 7-segment display. The 2 binary 7-segment display bytes are combined into a 2 byte word, inverted because the MCP23O17 is providing ground, and sent to the MCP23O17 for display.

During Wake the puzzle will turn on all the LED segments in both 7-segment displays and then turn them back off.

During Initialize the puzzle checks that all the switches are flipped down or off. If the difficulty is Easy, the switches are in base 2 order with the bottom 4 switchs handling from right to left 2^0 to 2^3 and the top 4 switches handling 2^4 to 2^7. If the difficulty is Medium, the bottom 4 switches are randomized and the top 4 switches are randomized. If the difficulty is Hard, all 8 switches are randomized.

During Play, the switches are read and its corresponding byte is displayed on the screen.  If the number is lower than the target number the display will alternate "Lo" and if the number is higher than the target number the display will alternate "Hi" with the number.
When the target number is discovered, all play stops and the puzzle is considered solved.

When the puzzle is solved the switches stop being read and the display shows in hex the target number. The hex to decimal table along the Hexadaisy edge can be used to convert the number from hex to decimal.

## Assembly

A piece of scrap 1/4 inch MDF was used to test the layout and fit all the parts. Once the layout for the puzzle was complete the puzzle was test fitted into the briefcase for testing with the other puzzles and control module. The MDF prototype was used as a template for the final 1/4 inch birch plywood. The final plywood was stained and clear coated.  Sides were added so the puzzle could be pulled out of the briefcase and set on the desk when connected directly to the computer for development. In addition wiring clips were added to the sides to keep the wires tidy.

Top view of the prototype Flip the Bits showing the placement of all the components.<br>
Picture of prototype Flip the Bits

Bottom view of the finished Flip the Bits showing the wire organization.<br>
Picture of finished Flip the Bits module

The holes for the switches are labeled in color indicating which switch should be attached where. The colors match resistor colors and are mapped 2^x where x is the resister color equivalent.

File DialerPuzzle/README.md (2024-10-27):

# Dialer

This puzzle reveals 7 digits. Well technically it uses 7 digits revealed by the other puzzles, but through dialing it reveals the correct order for those digits.

## Overview

This puzzle uses a rotary phone dialer, knife switch and a [DFPlayer](https://wiki.dfrobot.com/DFPlayer_Mini_SKU_DFR0299) from DF Robot. The Dialer is a nod to a "Busy Box" my dad made for us kids where he connected a rotary phone dialer to a group of 4 lights which would change when a number was dialed. The knife switch was used in our basement to connect a 300 baud modem to the phone line. The person upstairs would stomp on the floor, when the number was dialed, to tell the person in the basement to throw the knife switch. This was how we dialed into computers in the early 80s because the modem could not dial a number.

Picture of finished Dialer Puzzle module

## Hardware

The puzzle uses an [Arduino Nano](https://store-usa.arduino.cc/products/arduino-nano) as the processor and 3 digital pins are connected to switches. 1 pin is connected to the knife switch and the other 2 are connected to the phone dialer. The DFPlayer is connected to another 2 digital pins.

The Arduino Nano manages the state of the puzzle which is reflected in the [8mm NeoPixel](https://www.adafruit.com/product/1734) LED from Adafruit. See the [PhoneHome_PuzzleState.h](../PhoneHomeLib/PhoneHome_PuzzleState.h) for states and colors. The [PhoneHome_Definitions.h](../PhoneHomeLib/PhoneHome_Definitions.h) file contains the standard pins used by all Arduino Nanos.

The knife switch is connected to pin 4 on the Arduino. The Arduino initializes pin 4 enabling the internal pullup resistor. When the knife switch is closed it connects to Ground.

Only 2 switches inside the Rotary Phone Dialer are used. One indicates that dialing is in progress and is connected to pin 5 on the Arduino. The other toggles the pulses and is connected to pin 6 on the Arduino. Both pins are initialized with the internal pullup resistor enabled. When each switch closes it connects to Ground.

The DF Player is connected to pin 11 for transmitting serial messages and pin 10 for receiving serial messages. A speaker is attached to the DF Player.

The following is a Fritzing diagram of the connections.

Breadboard Diagram

The Dialer puzzle is soldered on one 5cmx7cm 2.54mm double sided prototype PCB circuit board. The Arduino Nano is placed on the board using headers. The connection to the bus is made at the top of the Arduino Nano using a 3 pin JST connector. The neopixel state indicator LED is connected using a 3 pin JST connector as well. A 2-pin JST connector is used to connect the knife switch. A 3-pin JST connector is used to connect the Rotary Phone Dialer.

The DF Player is also attached to the same prototype PCB circuit board as the Arduino Nano also using headers. The speaker is connected using a 2-pin JST connector.

Soldered Dialer Puzzle<br>
Picture of soldered Dialer Puzzle

## Software

The Arduino Nano manages the [State](../PhoneHomeLib/README.md#state-diagram) of the puzzle and communicates following the [Flow between Control Module and Slide into Home module](../PhoneHomeLib/README.md#sequence-diagram).

In addition to the libaries in [PhoneHomeLib](../PhoneHomeLib), the Dialer puzzle makes use of the [Bounce2](https://github.com/thomasfredericks/Bounce2) library from Thomas Fredericks and the [DFRobotDFPlayerMini](https://github.com/DFRobot/DFRobotDFPlayerMini) library from DFRobot.

All 3 switches rely on the Arduino's internal pull-up resistor. The knife switch, attached to pin 4, is the simplist using simple open/closed logic. In order to dial, the switch must be closed (connected to ground). When the switch is closed, the dialer can be used. Opening the switch will reset the dialer state and the number will have to be redialed. This is useful if a number is mis-dialed.
The dialer uses 2 switches which are both connected to ground. The switch indicating a number is being dialed is attached to pin 5. This indicates a number is in progress of being dialed. The number pulse switch is connected to pin 6. This is used to count the number of pulses which corresponds to the number being dialed. When the dialing switch opens the number is the number of pulses counted. Thank you [Playful Technology](https://www.youtube.com/@PlayfulTechnology) for saving me from going down the complicated rabbit hole of timing the pulses.

The DFRobot library is used for the Arduino Nano to communicate with the DFPlayer Mini. Communication occurs over a SoftwareSerial configuration using pins 10 & 11. The SoftwareSerial object is passed to the DFPlayer to use when communicating with the DFPlayer Mini.
An SD Card inserted into the DFPlayer Mini contains all the Sound bites to play.

| Folder | Sound |
| :---: | :---: |
| 1 | Dialtone |
| 2 | Ringing |
| 3 | Off Hook |
| 4 | Wrong Number |

During Wake the puzzle will briefly play the dialtone.

During Initialize the puzzle checks that the knife switche is open. If the knife switch is closed, an off-hook tone is played until the switch is opened. There is no modificiation to the number or game play based on difficulty applyed to the number expected to dial.

During Play, the knife switch is expected to closed and the number dialed. When the knife switch is closed a dialtone is played until the first number is dialed. The dialed number can be restarted by lifting the knife switch and then closing it which again plays the dialtone. All 7 numbers must be dialed in the correct order.
When the target number is dialed, a ringing sound is played.
If the wrong number is dialed, a wrong number sound is played.

When the puzzle is solved the switches stop being read.

## Assembly

A piece of scrap 1/4 inch MDF was used to test the layout and fit all the parts. Once the layout for the puzzle was complete the puzzle was test fitted into the briefcase for testing with the other puzzles and control module. The MDF prototype was used as a template for the final 1/4 inch birch plywood. The final plywood was stained and clear coated.  Sides were added so the puzzle could be pulled out of the briefcase and set on the desk when connected directly to the computer for development. In addition wiring clips were added to the sides to keep the wires tidy.

Top view of the prototype Dialer Puzzle showing the placement of all the components.<br>
Picture of prototype Dialer Puzzle

Bottom view of the finished Dialer Puzzle showing the wire organization.<br>
Picture of finished Dialer Puzzle module

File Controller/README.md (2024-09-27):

# Controller

This module manages the game play between all the puzzles and is the primary input for controlling the puzzles.

## Overview

The song that is played, when the game is won, is inspired by the early days of computing where many people wrote code to have their homemade computers play [The Entertainer](https://en.wikipedia.org/wiki/The_Entertainer_(rag)). When I first learned to program microcomputers on a [6502 based Datac 1000](https://oldcomputermuseum.com/datac-1000.html), the course taught you to write a program to play The Entertainer. My dad actually wrote the code to play songs on an Arduino and my son converted the music to the notes instructions.

The controller uses a LOLIN 2.4 Touch Screen display and a 20x4 character LCD Display. There is also a speaker to play the winning tune.

Picture of finished Controller module

## Hardware

The controller uses an [Arduino Nano](https://store-usa.arduino.cc/products/arduino-nano) as the processor, 2 displays, one with a touch screen, and one speaker.

The Arduino Nano manages the state of the puzzle which is reflected in the [8mm NeoPixel](https://www.adafruit.com/product/1734) LED from Adafruit. See the [PhoneHome_PuzzleState.h](../PhoneHomeLib/PhoneHome_PuzzleState.h) for states and colors. The [PhoneHome_Definitions.h](../PhoneHomeLib/PhoneHome_Definitions.h) file contains the standard pins used by all Arduino Nanos.

The [Liquid Crystal Display](https://www.digikey.com/en/products/detail/sunfounder/4411-CN0296D-ND/18668625) shows instructions and is connected using the standard I2C pins. The Arduino SDA(pin A4/D18) and SCL(pin A5/D19) are connected to the LCD I2C Hat.

The [LOLIN TFT-2.4 Touch Screen](https://www.aliexpress.us/item/2251832733414978.html) is used for input and game status. It uses the ILI9341 for the display and XPT2026 for the capacitive touch. The Touch Screen is attached using SPI following the pins described in the [datasheet](https://www.wemos.cc/en/latest/d1_mini_shield/tft_2_4.html).
The LOLIN TFT runs on 3.3v while the Arduino Nano is running on 5v. The TFT is powered using the 3.3v supplied by the Arduino Nano. The data lines from the Arduino to the TFT go through a voltage divide to step the voltage from 5v to 3.3v. A pair of 1K ohm and 2K ohm resistors divide the voltage by 2/3rds. The MISO/CIPO signal to the Arduino from the TFT is left at 3.3v since the Arduino can accept 3.3v as input.

The following pin mappings are used:

| Description | Touch Screen Pin | Arduino Pin |
| :---: | :---: | :---: |
| MOSI/COPI | D7 | D11 |
| MISO/CIPO | D6 | D12 |
| SCK | D5 | D13 |
| TFT_DC | D8 | D10 |
| TFT_CS | D0 | D9 |
| TS_CS | D3 | D7 |
| RST | RST | D8 |

An [Adafruit 4 ohm speaker](https://www.adafruit.com/product/3351) is attached to pin 4 of the Arduino and ground.

The following is a Fritzing diagram of the connections.

Breadboard Diagram

The Controller is soldered on one 5cmx7cm 2.54mm double sided prototype PCB circuit board. The Arduino Nano is placed on the board using headers. The connection to the bus is made at the top of the Arduino Nano using a 3-pin JST connector. The neopixel state indicator LED is connected using a 3-pin JST connector as well.

The female headers on the LOLIN TFT are connected to the prototype PCB with male headers.

The I2C connection to the 20x4 char LCD is done through a row of 4 headers and a 4 wire jumper cable.

The speaker is attached using a 2-pin JST.

Soldered Controller<br>
Picture of soldered Controller

## Software

The Arduino Nano manages the [State](../PhoneHomeLib/README.md#state-diagram) of the puzzle and communicates following the [Flow between Control Module and Slide into Home module](../PhoneHomeLib/README.md#sequence-diagram).

In addition to the libaries in [PhoneHomeLib](../PhoneHomeLib), the Dialer puzzle makes use of the [LiquidCrystal_I2C](https://www.arduino.cc/reference/en/libraries/liquidcrystal/) library included in the Arduino IDE. The Controller also uses the [Adafruit ILI9341](ihttps://github.com/adafruit/Adafruit_ILI9341) library from Adafruit for displaying information on the screen and the [XPT2046 Touchscreen](https://github.com/PaulStoffregen/XPT2046_Touchscreen) library from Paul Stoffregen to receive touch input from the player.

When the briefcase is first powered on, the Controller waits a couple of seconds and then starts to "Wake Up" the puzzles. Progress is displayed on the Touch Screen. When a puzzle Acknowleges the Wake up request, the box is turned green and displays the short name returned. If a puzzle does not Acknowledge the Controller due to a time-out, the box is turned red on the display.

The difficulty choices are then displayed for the player to select. If the Player selects Easy, only one phone number is used and the puzzles are played in order. If the Player selects Medium, the phone number is selected from a few numbers and the puzzles are played in random order. If the Player selects Hard, the phone number is selected from all possible phone numbers, the number is then randomized, and the puzzles are played in random order.

Once the difficulty has been selected a clock is displayed and the first puzzle is Started.
When the puzzle is completed the game will pause with instructions on how to decode the number. When the Player presses Next on the Touch Screen the next puzzle will be Started. If a puzzle does not require a pause, it will inform the Controller that none is required.

The Controller sends a Start command along with the number(s) the puzzle should use to solve. If the puzzle requires initialization, it informs the Controller which then displays the initialization instructions send by the puzzle on the 20x4 char LCD. When the puzzle is playing, it may also send playing instructions to the Controller to be displayed on the 20x4 char LCD. When the puzzle has been solved and requires instructions to decode the number, the puzzle will send the instructions for the Controller to display on the 20x4 char LCD.

When the last puzzle (Dialer Puzzle) has been solved, the Controller will play a congratulations tune.

## Assembly

A piece of scrap 1/4 inch MDF was used to test the layout and fit all the parts. Once the layout for the puzzle was complete the puzzle was test fitted into the briefcase for testing with the other puzzles and control module. The MDF prototype was used as a template for the final 1/4 inch birch plywood. The final plywood was stained and clear coated.  Sides were added so the puzzle could be pulled out of the briefcase and set on the desk when connected directly to the computer for development. In addition wiring clips were added to the sides to keep the wires tidy.

Top view of the prototype Controller showing the placement of all the components.<br>
Picture of prototype Controller

Bottom view of the finished Controller showing the wire organization.<br>
Picture of finished Controller module

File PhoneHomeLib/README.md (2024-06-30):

# Phone Home Library

## Overview

This Library is included by all the modules to provide standard definitions and common code.

There are 3 key include files and a test sketch.

- [**PhoneHome_Definitions.h**](PhoneHome_Definitions.h) defines the common pins to be used by all of the modules.
- [**PhoneHome_Command.h**](PhoneHome_Command.h) handles all command communication into or out of the module. Communication can happen over PJON or the USB Serial connection.
- [**PhoneHome_PuzzleState.h**](PhoneHome_PuzzleState.h) manages the puzzle states for the puzzle modules. It also handles displaying the state using colors on the neopixel.
- [**PhoneHomeLib.ino**](PhoneHomeLib.inos) is a test sketch to test if the serial handling and state management is functioning.

## Architecture

Each module uses a single Arduino Nano to handle its part of the puzzle. There are 3 pins reserved for every module. Pin *A7* is left floating and used to help with generating a seed for randomization. Pin *A0* is used by the puzzle modules to display the state of the puzzle. In the control module this pin is not used. Communication happens over Pin *A1* for all modules.

### Communication

Communication happens using the [PJON \(Padded Jitterning Operative Network\)](https://github.com/gioblu/PJON) protocol over a single wire using [SoftwareBitBang](https://github.com/gioblu/PJON/tree/master/src/strategies/SoftwareBitBang). A common library, [PhoneHome_Command.h](PhoneHome_Command.h), is used to establish a common communication language between the **Control Module** and the puzzle modules.
The *PhoneHome_Command.h* library can accept command over both the PJON wire as well as over the USB Serial connection. Responses are always sent over both PJON and USB Serial. This flexibility allows a module to be tested in isolation from the rest of the briefcase.
Here is a list of the possible commands:

| Command | Format | Description |
| --- | --- | --- |
| **W**ake | `W` | From Control to Puzzle to Wake Up |
| **A**cknowledge | `A[short name]`<BR>`[short name]`=module | From Puzzle to Control acknowledging the Wake Up |
| **S**tart | `SD###`<BR>`D`=Difficulty<BR>`###`=number | From Control to Puzzle to starting playing at the requested Difficulty using the ###s provided. |
| **I**nitialize | `I[long name]`<BR>`[long name]`=module | From Puzzle to Control to ask player to initialize the puzzle using instructions provided. |
| **P**laying | `P[long name]`<BR>`[long name]`=module | From Puzzle to share state with Control and display playing instructions. |
| **D**one | `D` or `DY`<BR>`Y`=instructions | From Puzzle to Control to indicate puzzle is solved and to optionally display decoding instructions. |
| **L**ine | `L[display line]`<BR>`[display line]`=20 char for LCD | From Puzzle to Control to share 1 line of instuction text to display on LCD. |
| **N**ext | `N` | From Control to Puzzle requesting the next line of text to display on the LCD. |
| **T**une | `T` | Request to put the puzzle in Tune state. |

One of the risks of a single wire protocol is collisions with multiple devices trying to communicate at once. This is handled by following a request-response pattern and only having one puzzle active at a time. The **Control Module** activates each puzzle when it is that puzzle's time to be played which removes communication conflicts. The state is synchronized between the puzzle and **Control Module** using the following sequence diagram and state machine:

#### Sequence Diagram
```mermaid
---
title: Control Module and Puzzle Interactions
---
sequenceDiagram
  participant control as Control Module
  participant puzzle as Puzzle

  Note right of puzzle: On Power, Set Puzzle State to "Startup"
  control->>puzzle: 'W'ake Up
  activate puzzle
  puzzle->>puzzle: Check and Flash display
  puzzle->>puzzle: Set State to "Ready"
  puzzle->>control: 'A'cknowledge and Ready to Play
  deactivate puzzle

  control->>puzzle: 'S'tart playing with these number(s)
  activate puzzle

  alt Puzzle needs Initialized
    puzzle->>puzzle: Set State to "Initialize"
    puzzle-->>control: 'I'nitialization needed
    activate control
    Note right of puzzle: Display how to Initialize Puzzle
    loop Up to 4 display lines
      control-->>puzzle: 'N'ext line of text
      activate puzzle
      puzzle-->>control: 'L'ine of text
      deactivate puzzle
    end
    deactivate control
    puzzle->>puzzle: Wait for Player to Initialize Puzzle
  end

  puzzle->>puzzle: Set State to "Playing"
  puzzle-->>control: 'P'laying the game
  activate control
  Note right of puzzle: Display how to Play Puzzle
  loop Up to 4 display lines
    control-->>puzzle: 'N'ext line of text
    activate puzzle
    puzzle-->>control: 'L'ine of text
    deactivate puzzle
  end
  deactivate control

  puzzle->>puzzle: Wait for Player to Solve Puzzle

  puzzle->>puzzle: Set State to "Solved"
  puzzle->>control: 'D'one playing
  activate control
  Note right of puzzle: Display how to Interpret Number
  loop Up to 4 display lines
    control-->>puzzle: 'N'ext line of text
    activate puzzle
    puzzle-->>control: 'L'ine of text
    deactivate puzzle
  end
  deactivate control

  deactivate puzzle

```

### State

Each puzzle manages their state and shares that state with the **Control Module**. The following describes each of the puzzle module states:

- **Starting** state indicates the module has performed the setup functions and is waiting for the **Control Module** to acknowledge its presence.
- **Ready** state indicates the puzzle is ready to play. This state occurs after the **Control Module** has acknowledged the module's presence and the module performed the self checks.
- **Initialize** state indicates the puzzle needs the player to reset or initialize the puzzle. When the **Control Module** request the puzzle to play, there may be a need for player interaction to reset the puzzle so play can start.
- **Playing** state indicates the player is playing the puzzle. This state is entered after the Initialization steps are complete.
- **Solved** state indicates the player has solved the puzzle. The answer remains on the display.
- **Tuning** state indicates the puzzle has been placed in tuning mode.

#### State Diagram
```mermaid
---
title: Puzzle State Diagram
---
stateDiagram-v2
  direction TB

  state needsInitialized <<choice>>

  [*] --> Startup: Power Up
  Startup --> Ready: Control Wakes Up Puzzle
  Ready --> needsInitialized: Control Starts Puzzle
  needsInitialized --> Initialize: Puzzle<BR>needs to be<BR>Initialized
  needsInitialized --> Playing: Puzzle<BR>is ready to<BR>Play
  Initialize --> Playing: Puzzle Initialized
  Playing --> Done: Puzzle is Solved
  Done --> Ready: Control Wakes Puzzle<br>for another game

  classDef purple fill:#f0f,font-weight:bold
  classDef blue fill:#00F,color:white,font-weight:bold
  classDef red fill:#F00,color:white,font-weight:bold
  classDef yellow fill:#FF0,font-weight:bold
  classDef green fill:#0F0,font-weight:bold
  classDef cyan fill:#0FF,font-weight:bold

  class Startup purple
  class Ready blue
  class Initialize red
  class Playing yellow
  class Done green

```

## Attribution

I would like to thank [Playful Technology](https://www.youtube.com/@PlayfulTechnology) on YouTube for [introducing me to PJON as a cross module communication tool](https://www.youtube.com/watch?v=u8giZveqlxs&list=PLogiUurtMYtSxku2Itst0msCv8MC2w14P&index=1).

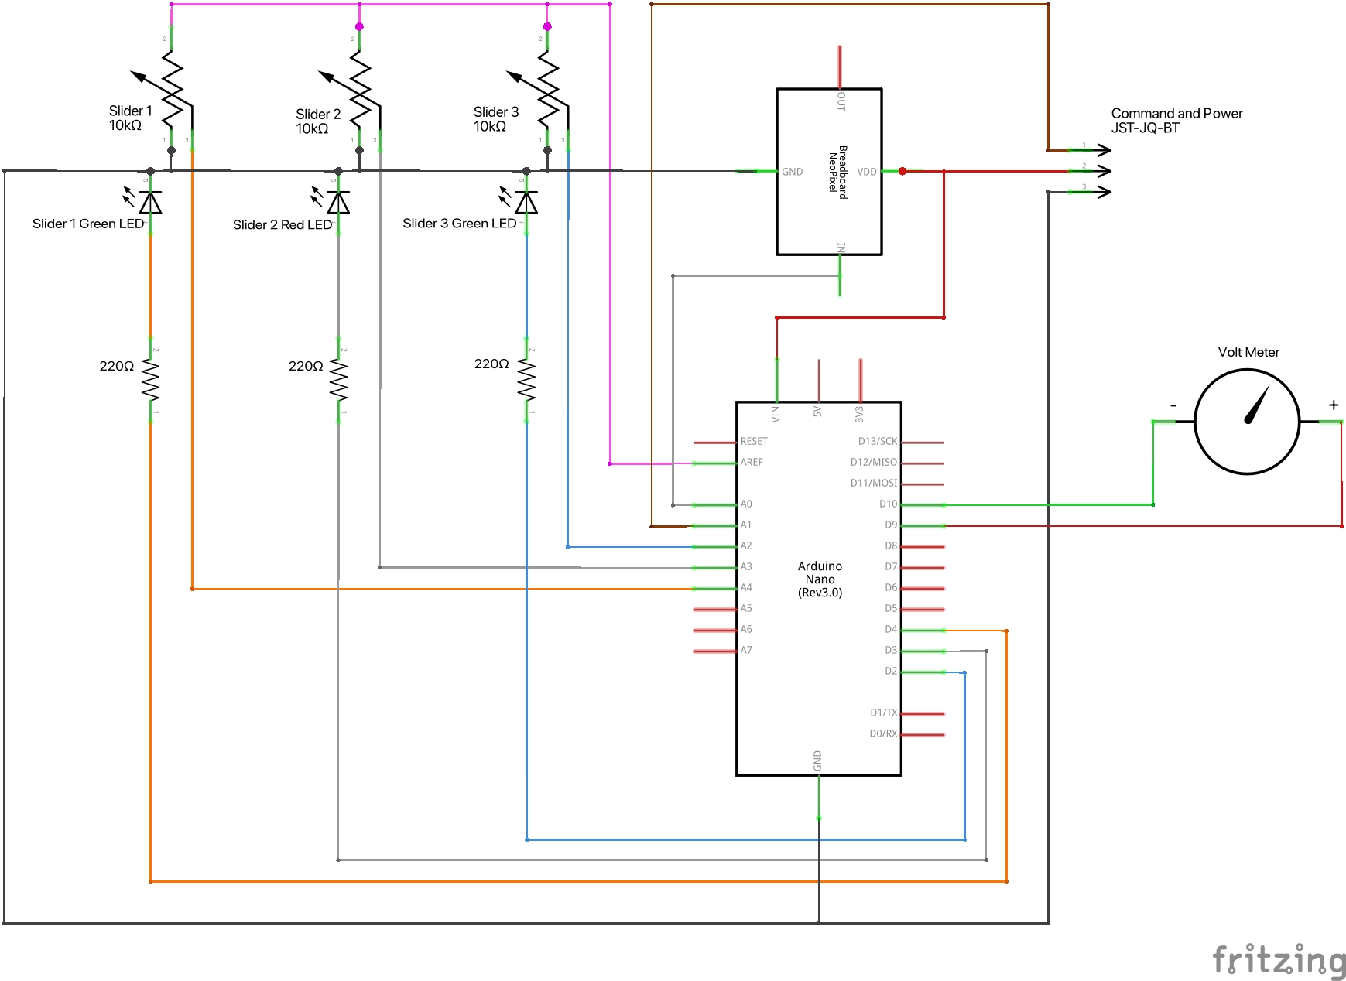
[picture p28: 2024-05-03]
images/Slider_Schematic.jpg

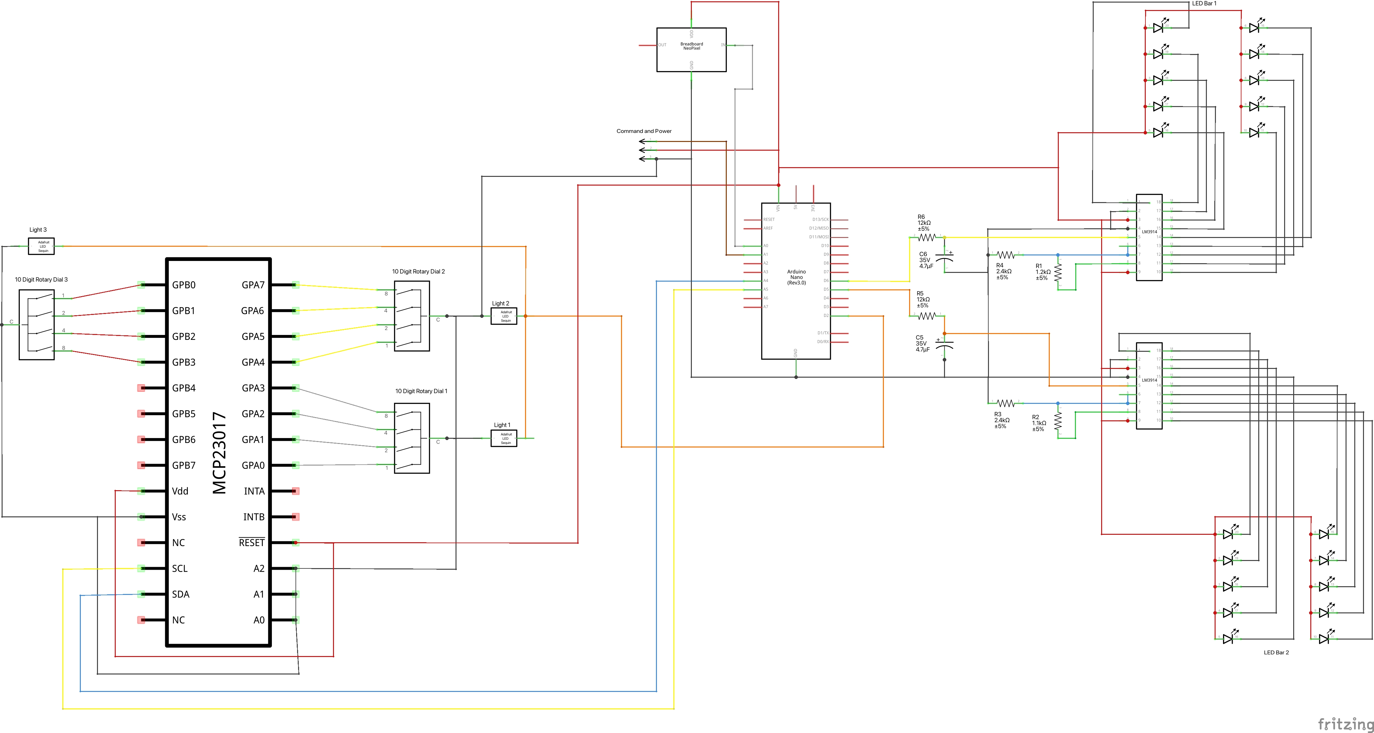
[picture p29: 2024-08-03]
images/SpinDigit_Breadboard_Schematic.jpg

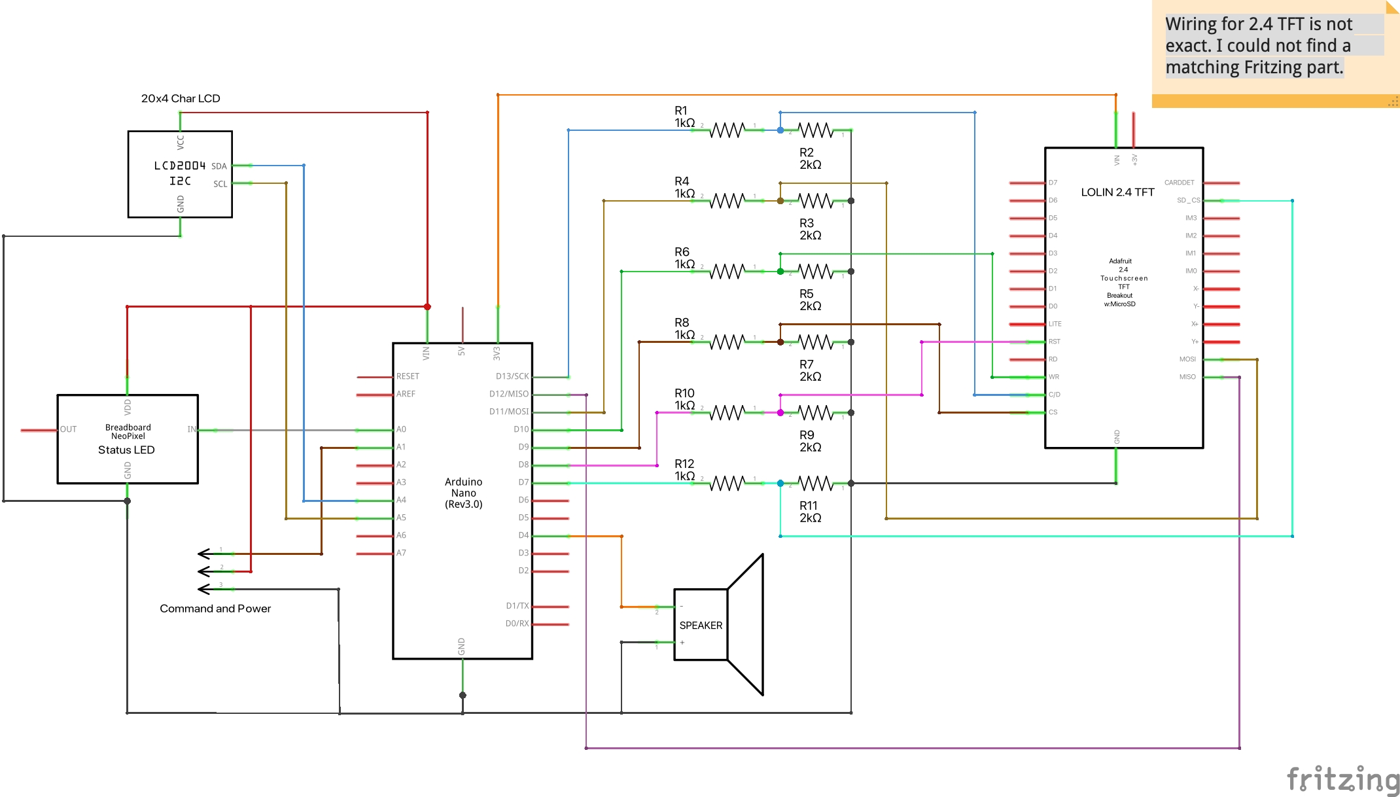
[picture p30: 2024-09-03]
images/Controller_Breadboard_Schematic.jpg

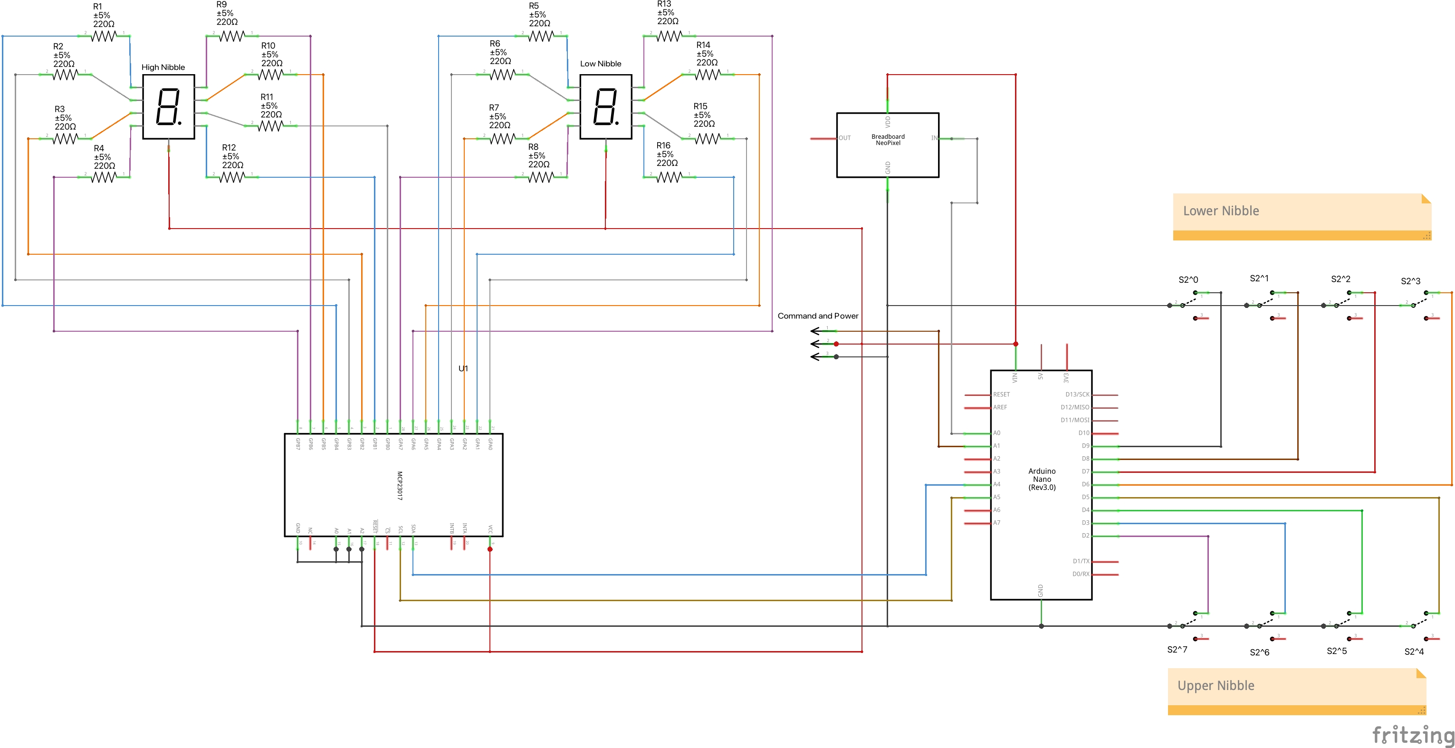
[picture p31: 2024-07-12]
images/FlipBits_Breadboard_Schematic.jpg

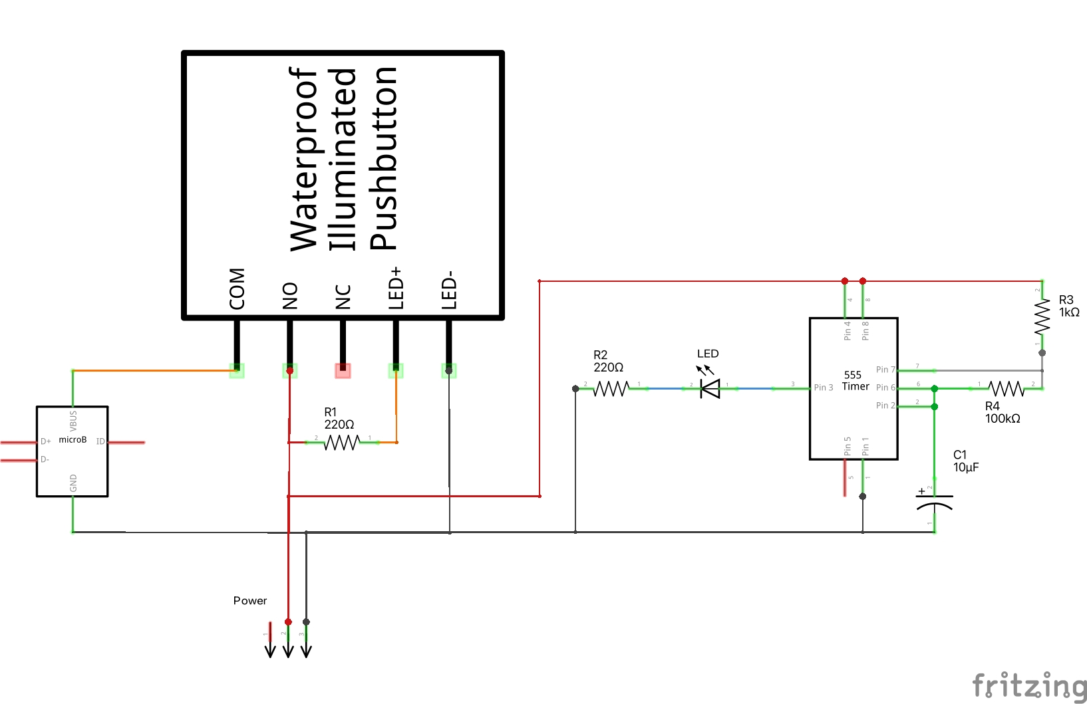
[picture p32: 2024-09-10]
images/Power_Breadboard_Schematic.jpg

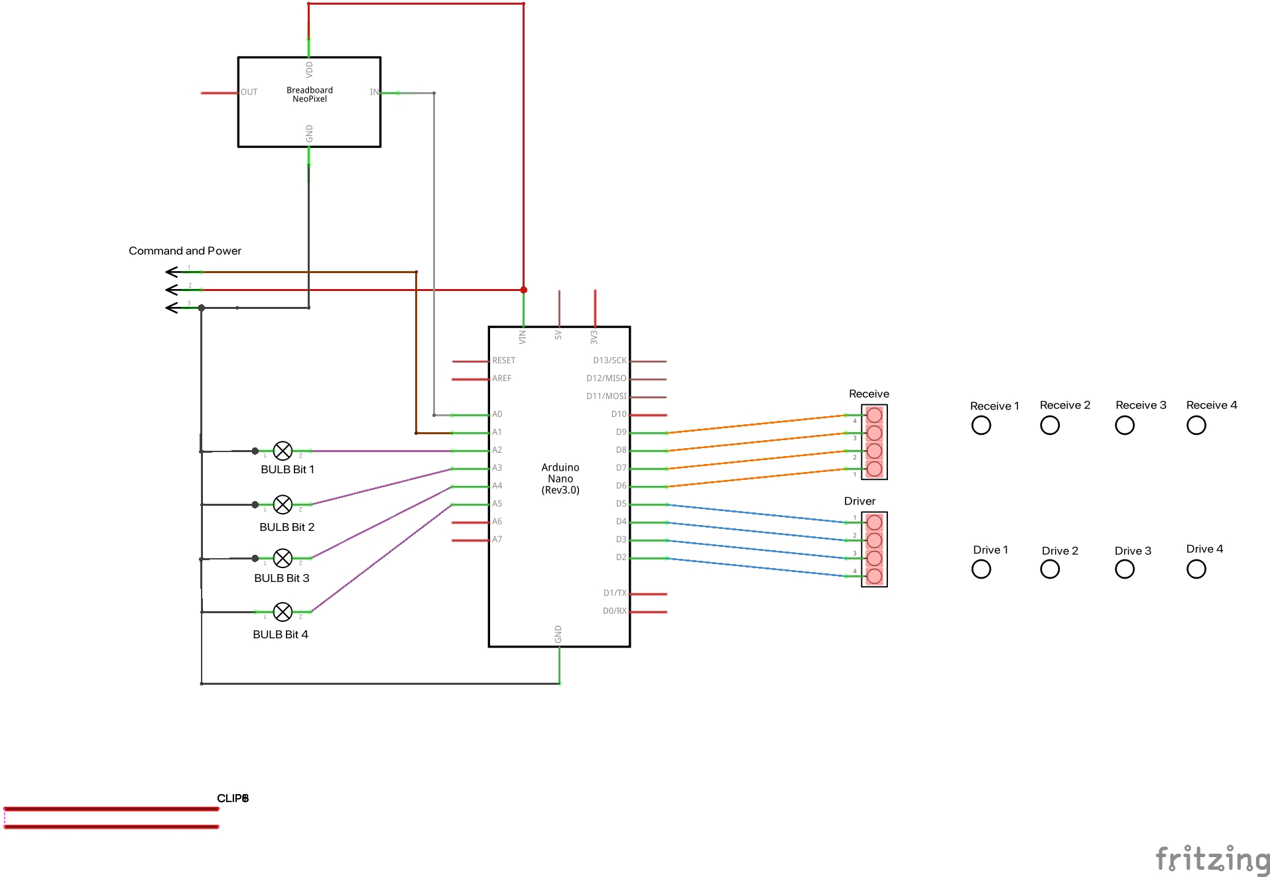
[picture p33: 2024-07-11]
images/HookMeUp_Schematic.jpg

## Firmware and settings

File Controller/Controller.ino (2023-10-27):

// Connect Wires
// Receive Pins (top row of pins) and bit lights should always match
// The driver pins will be randomized

#define PHONEHOME_CONTROLLER

#include <Arduino.h>
#include <PhoneHome_Definitions.h>
#include <PhoneHome_Command.h>
#include <PhoneHome_PuzzleState.h>
//#include <Wire.h> 
#include <LiquidCrystal_I2C.h>
//#include <Adafruit_GFX.h>
//#include <SPI.h>
#include <Adafruit_ILI9341.h>
#include <XPT2046_Touchscreen.h>
#include "Melody.h"
#include "Entertainer.h"
#include "Instructions.h"

// These definitions make the code more readable from the controller perspective
// allowing for library reuse and clarity of controller vs puzzle
#define ControllerStates        PuzzleStates
#define controllerState         puzzleState
#define setControllerState      setPuzzleState
#define controllerStatesString  puzzleStatesString
#define setupControllerStatus   setupPuzzleStatus

// Puzzle definitions
const uint8_t   ControllerId  = CONTROL_ID;
const char* ControllerShortName = "Control";
const char* ControllerName = "Controller";
//bool controlInitialized = false;
#define MAX_MINUTES 30

//Speaker
#define SPEAKER_PIN 4

// Set the LCD address to 0x27 for a 16 chars and 2 line display
LiquidCrystal_I2C lcd(0x27,20,4);

// This is calibration data for the raw touch data to the screen coordinates
#define TS_MINX 500
#define TS_MINY 500
#define TS_MAXX 3300
#define TS_MAXY 3500

// Touch Screen definitions
#define TS_CS 7   // Connected to LOLIN pin D3
XPT2046_Touchscreen ts(TS_CS);

// TFT Screen definitions
#define TFT_RST   8    // Connected to LOLIN pin RST
#define TFT_CS    9    // Connected to LOLIN pin D3
#define TFT_DC    10   // Connected to LOLIN pin D8
//#define TFT_MOSO      // Connected to LOLIN pin D6
//#define TFT_MOSI     // Connected to LOLIN pin D7
//#define TFT_SCK      // Connected to LOLIN pin D5
// initialize ILI9341 TFT library
Adafruit_ILI9341 tft = Adafruit_ILI9341(TFT_CS, TFT_DC, TFT_RST);
//Adafruit_ILI9341 tft = Adafruit_ILI9341(TFT_CS, TFT_DC);
#define TFT_WIDTH 320
#define TFT_HEIGHT 240

// Display order
const static uint8_t puzzleDisplayOrder[] = {SLIDER_ID, CONTROL_ID, FLIPBITS_ID, WIRES_ID, PHONE_ID, SPINDIGIT_ID};
//const String puzzleDisplayNames[] = {"Slider", "Control", "Flip", "Wires", "Phone", "Spin"};
#define PUZZLE_DISPLAY_ORDER_LENGTH 6



char puzzleDifficulty = DIFFICULTY_EASY;
uint8_t difficulty = 0;
const char* difficultyDisplayNames[] = {"Easy", "Medium", "Hard"};
const uint16_t difficlutyDisplayColors[] = {ILI9341_GREEN, ILI9341_YELLOW, ILI9341_RED};
#define DIFFCULTY_DISPLAY_LENGTH 3

bool wasTouched = false;

typedef enum WakeStates {Unknown, Asked, Awake, Timedout} WakeStates;
const uint16_t wakeStateColors[] = {ILI9341_WHITE, ILI9341_YELLOW, ILI9341_GREEN, ILI9341_RED};

WakeStates puzzleWakeStatus[ID_ARRAY_LENGTH];

// Game Order
#define PUZZLE_PLAY_LENGTH 5
#define TARGET_NUMBER_LENGTH 7
#define MAX_TARGET_NUMBERS 3
const  uint8_t defaultPlayOrder[PUZZLE_PLAY_LENGTH] = {SLIDER_ID, WIRES_ID, FLIPBITS_ID, SPINDIGIT_ID, PHONE_ID};
uint8_t puzzlePlayOrder[PUZZLE_PLAY_LENGTH];
const char* targetPuzzleNumbers[MAX_TARGET_NUMBERS] = {"7950163", "7955769", "8675309"};
uint8_t targetNumberPos = 0;
const uint8_t difficultyPuzzleChoice[DIFFCULTY_DISPLAY_LENGTH] = {1, 2, MAX_TARGET_NUMBERS};
char randomPuzzleNumber[TARGET_NUMBER_LENGTH+1];
uint8_t nextNumberPosition = 0;
byte puzzleNumberSize[ID_ARRAY_LENGTH] = {0, 0, 0, 0, 0, 0, 0};   // Based on ID numbers

//const char* targetNumber = "7950163";
uint8_t currentPuzzle = 0;
uint8_t currentPuzzleID = 0;
//char currentPuzzleShortName[10] = "";
//char currentPuzzleLongName[21] = "";
uint8_t elapsedMinutes = 0;
uint8_t elapsedSeconds = 0;
unsigned long lastMillis = 0;
uint8_t lcdDisplayLine = 0;
bool puzzleDone = false;
bool doneInstructions = false;
bool showNextArrow = false;

//PuzzleDefinition *currentPuzzleDefinition;
bool commandSent = false;
unsigned long commandSentAt = 0;
bool wakeTimeout = false;
#define TIMEOUT_MILLIS 5000

#define BACKGROUND_COLOR  ILI9341_BLACK
#define PADDING           4

// Puzzle display grid constants
#define PUZZLE_TEXT_COLOR       ILI9341_BLACK
#define PUZZLE_WIDTH            100
#define PUZZLE_HEIGHT           100
#define PUZZLE_RADIUS           10
#define PUZZLE_PADDING          5
#define PUZZLE_TEXT_SIZE        2
#define PUZZLE_TEXT_CHAR_HEIGHT 16
#define PUZZLE_TEXT_CHAR_WIDTH  12
#define PUZZLE_OFFSET_X         5
#define PUZZLE_OFFSET_Y         20

// Difficulty display grid constants
#define DIFFICULTY_TEXT_COLOR       ILI9341_BLACK
#define DIFFICULTY_WIDTH            100
#define DIFFICULTY_HEIGHT           200
#define DIFFICULTY_RADIUS           20
#define DIFFICULTY_PADDING          5
#define DIFFICULTY_TEXT_SIZE        2
#define DIFFICULTY_TEXT_CHAR_HEIGHT 16
#define DIFFICULTY_TEXT_CHAR_WIDTH  12
#define DIFFICULTY_TEXT_Y           (TFT_HEIGHT - DIFFICULTY_TEXT_CHAR_HEIGHT)/2
#define DIFFICULTY_OFFSET_X         5
#define DIFFICULTY_OFFSET_Y         20

#define TEXT_SIZE         3
#define TEXT_CHAR_HEIGHT  24
#define TEXT_CHAR_WIDTH   18

#define LINE_COLOR  ILI9341_MAGENTA
#define LINE_HEIGHT 4

#define NAME_COLOR    ILI9341_CYAN
#define NAME_START_X  0
#define NAME_START_Y  PADDING

#define DIFF_START_X 0
#define DIFF_START_Y NAME_START_Y + TEXT_CHAR_HEIGHT + PADDING

#define TOP_LINE_Y      DIFF_START_Y + TEXT_CHAR_HEIGHT + PADDING
#define TOP_LINE_END_Y  TOP_LINE_Y + LINE_HEIGHT

#define STATUS_COLOR    ILI9341_ORANGE
#define STATUS_START_X  0
#define STATUS_START_Y  TFT_HEIGHT - TEXT_CHAR_HEIGHT - PADDING

#define BOT_LINE_Y STATUS_START_Y - PADDING - LINE_HEIGHT

#define TIME_COLOR        ILI9341_WHITE
#define TIME_TEXT_SIZE    9
#define TIME_CHAR_HEIGHT  72
#define TIME_CHAR_WIDTH   54
#define TIME_MIDDLE_Y     (TOP_LINE_END_Y + BOT_LINE_Y)/2
#define TIME_Y            TIME_MIDDLE_Y - (TIME_CHAR_HEIGHT/2)
#define TIME_COLON_X      (TFT_WIDTH - TIME_CHAR_WIDTH)/2
#define TIME_MINUTES_X    TFT_WIDTH/2 - (TIME_CHAR_WIDTH*2.5)
#define TIME_SECONDS_X    TFT_WIDTH/2 + (TIME_CHAR_WIDTH/2)

#define NEXT_COLOR            ILI9341_PINK
#define NEXT_CIRCLE_X         TFT_WIDTH/2
#define NEXT_CIRCLE_Y         TIME_MIDDLE_Y
//#define NEXT_CIRCLE_RADIUS  (BOT_LINE_Y - TOP_LINE_END_Y)/2 - (PADDING*4)
#define NEXT_CIRCLE_RADIUS    60
#define NEXT_TRIANGLE_LEFT_X  (TFT_WIDTH/2) - 35
#define NEXT_TRIANGLE_TOP_Y   TIME_MIDDLE_Y - 45
#define NEXT_TRIANGLE_BOT_Y   TIME_MIDDLE_Y + 45
#define NEXT_TRIANGLE_RIGHT_X (TFT_WIDTH/2) + NEXT_CIRCLE_RADIUS - PADDING
#define NEXT_TRIANGLE_RIGHT_Y TIME_MIDDLE_Y
#define NEXT_TEXT_COLOR       ILI9341_BLACK
#define NEXT_TEXT_SIZE        3
#define NEXT_TEXT_CHAR_HEIGHT 24
#define NEXT_TEXT_CHAR_WIDTH  18
#define NEXT_TEXT_LENGTH      4
#define NEXT_TEXT_Y           TIME_MIDDLE_Y - (NEXT_TEXT_CHAR_HEIGHT / 2)+3
#define NEXT_TEXT_X           NEXT_TRIANGLE_LEFT_X + 3



/*
 * Print a set of 4 lines from PROGMEM to the LCD display
 */
void printLCD(const char *const lines[]) {
  char lineBuffer[21];
  lcd.clear();
  for (int lineNum=0; lineNum<4; lineNum++) {
    strcpy_P(lineBuffer, (char *)pgm_read_word(&(lines[lineNum])));
    lcd.setCursor(0, lineNum);
    lcd.print(lineBuffer);
  }
}


void printPuzzleNameTFT(char*  nameText) {
  tft.fillRect(NAME_START_X, NAME_START_Y, TFT_WIDTH, TEXT_CHAR_HEIGHT, BACKGROUND_COLOR);
  tft.setTextSize(TEXT_SIZE);
  tft.setTextColor(NAME_COLOR);
  uint16_t textWidth = strlen(nameText) * TEXT_CHAR_WIDTH;
  tft.setCursor((TFT_WIDTH-textWidth)/2, NAME_START_Y);
  tft.print(nameText);
}

void printPuzzleStatusTFT(const char*  statusText) {
  tft.fillRect(STATUS_START_X, STATUS_START_Y, TFT_WIDTH, TEXT_CHAR_HEIGHT, BACKGROUND_COLOR);
  tft.setTextSize(TEXT_SIZE);
  tft.setTextColor(STATUS_COLOR);
  uint16_t textWidth = strlen(statusText) * TEXT_CHAR_WIDTH;
  tft.setCursor((TFT_WIDTH-textWidth)/2, STATUS_START_Y);
  tft.print(statusText);
}

void printColonTFT() {
  tft.setTextSize(TIME_TEXT_SIZE);
  tft.setTextColor(TIME_COLOR);
  tft.setCursor(TIME_COLON_X, TIME_Y);
  tft.print(":");
}

void printNextArrow() {
  tft.drawCircle(NEXT_CIRCLE_X, NEXT_CIRCLE_Y, NEXT_CIRCLE_RADIUS, NEXT_COLOR);
  tft.fillTriangle(NEXT_TRIANGLE_LEFT_X, NEXT_TRIANGLE_TOP_Y, NEXT_TRIANGLE_LEFT_X, NEXT_TRIANGLE_BOT_Y, NEXT_TRIANGLE_RIGHT_X, NEXT_TRIANGLE_RIGHT_Y, NEXT_COLOR);
  tft.setTextColor(NEXT_TEXT_COLOR);
  tft.setTextSize(NEXT_TEXT_SIZE);
  tft.setCursor(NEXT_TEXT_X, NEXT_TEXT_Y);
  tft.print(F("NEXT"));
}

void printMinutesTFT() {
  tft.fillRect(TIME_MINUTES_X, TIME_Y, TIME_CHAR_WIDTH*2, TIME_CHAR_HEIGHT, BACKGROUND_COLOR);
  tft.setTextSize(TIME_TEXT_SIZE);
  tft.setTextColor(TIME_COLOR);
  tft.setCursor(TIME_MINUTES_X, TIME_Y);
  if (elapsedMinutes < 10) {
    tft.print("0");
  }
  tft.print(elapsedMinutes);
  tft.flush();
  if (showNextArrow) {
    printNextArrow();
  }
}


void printSecondsTFT() {
  tft.fillRect(TIME_SECONDS_X, TIME_Y, TIME_CHAR_WIDTH*2, TIME_CHAR_HEIGHT, BACKGROUND_COLOR);
  tft.setTextSize(TIME_TEXT_SIZE);
  tft.setTextColor(TIME_COLOR);
  tft.setCursor(TIME_SECONDS_X, TIME_Y);
  if (elapsedSeconds < 10) {
    tft.print("0");
  }
  tft.print(elapsedSeconds);
  tft.flush();
  if (showNextArrow) {
    printNextArrow();
  }
}


bool addSecond() {
  elapsedSeconds++;
  if (elapsedSeconds >= 60) {
    elapsedSeconds = 0;
    elapsedMinutes++;
    printMinutesTFT();
  }
  printSecondsTFT();
  return (elapsedMinutes >= MAX_MINUTES);
}


void showTime() {
  showNextArrow = false;
  tft.fillRect(0, NEXT_CIRCLE_Y-NEXT_CIRCLE_RADIUS-1, TFT_WIDTH, (NEXT_CIRCLE_RADIUS*2)+2, BACKGROUND_COLOR);
  printColonTFT();
  printSecondsTFT();
  printMinutesTFT();
}

void showNext() {
  showNextArrow = true;
  printNextArrow();
}


void showPlayFTF() {
  tft.fillScreen(BACKGROUND_COLOR);

  uint16_t textWidth = strlen(difficultyDisplayNames[difficulty]) * TEXT_CHAR_WIDTH;
  tft.setTextSize(TEXT_SIZE);
  tft.setCursor((TFT_WIDTH-textWidth)/2, DIFF_START_Y);
  tft.setTextColor(difficlutyDisplayColors[difficulty]);
  tft.print(difficultyDisplayNames[difficulty]);

  tft.fillRect(NAME_START_X, TOP_LINE_Y, TFT_WIDTH, LINE_HEIGHT, LINE_COLOR);
  //tft.drawFastHLine(0, STATUS_LINE_Y-5, TFT_WIDTH, LINE_COLOR);
  tft.fillRect(STATUS_START_X, BOT_LINE_Y, TFT_WIDTH, LINE_HEIGHT, LINE_COLOR);

  showTime();
}

void playMusic(int speakerPin, Note music[]) {
    
  // iterate over the notes of the melody:
  int thisNote=0;
  while (music[thisNote].note != END_NOTES) {
  
    int dur = music[thisNote].duration;
    
    // to calculate the note duration, take one second 
    // divided by the note type.
    //e.g. quarter note = 1000 / 4, eighth note = 1000/8, etc.
    int noteDuration = 1000/music[thisNote].duration;
    tone(speakerPin, music[thisNote].note, noteDuration);
  
    // to distinguish the notes, set a minimum time between them.
    // the note's duration + 30% seems to work well:
    int pauseBetweenNotes = noteDuration * 1.30;
    delay(pauseBetweenNotes);

    // stop the tone playing:
    noTone(speakerPin);
    thisNote++;
  }
}

// Draw just the one puzzle
void drawWakeStatus (uint8_t puzzle, char *puzzleName) {
    uint8_t thisPuzzleID = puzzleDisplayOrder[puzzle];
    uint8_t row = puzzle / 3;
    uint8_t col = puzzle % 3;
    uint16_t startX = col*(PUZZLE_WIDTH+PUZZLE_PADDING) + PUZZLE_OFFSET_X;
    uint16_t startY = row*(PUZZLE_HEIGHT+PUZZLE_PADDING) + PUZZLE_OFFSET_Y;
//    int width = PUZZLE_WIDTH;
//    int height = PUZZLE_HEIGHT;

    tft.fillRoundRect(startX, startY, PUZZLE_WIDTH, PUZZLE_HEIGHT, PUZZLE_RADIUS, wakeStateColors[puzzleWakeStatus[thisPuzzleID]]);

    // Draw gap
    //startX += PUZZLE_PADDING;
    //startY += PUZZLE_PADDING;
    //width -= PUZZLE_PADDING*2;
    //height -= PUZZLE_PADDING*2;
    //tft.fillRoundRect(startX, startY, width, height, PUZZLE_RADIUS, ILI9341_BLACK);

    // Draw Center
    //startX += PUZZLE_PADDING;
    //startY += PUZZLE_PADDING;
    //width -= PUZZLE_PADDING*2;
    //height -= PUZZLE_PADDING*2;
    //uint16_t boxBackgroundColor = ILI9341_DARKGREY;
    //tft.fillRoundRect(startX, startY, width, height, PUZZLE_RADIUS, boxBackgroundColor);

    // Draw Labels
    startX += (PUZZLE_WIDTH - (strlen(puzzleName) * PUZZLE_TEXT_CHAR_WIDTH))/2;
    startY += (PUZZLE_HEIGHT-PUZZLE_TEXT_CHAR_HEIGHT)/2;
    tft.setTextSize(PUZZLE_TEXT_SIZE);
    tft.setTextColor(PUZZLE_TEXT_COLOR);
    tft.setCursor(startX, startY);
    tft.print(puzzleName);

}

// Draw all the puzzles
void drawWakeStatus () {
  char wakingPuzzleName[] = "??";
  for (uint8_t puzzle=0; puzzle<PUZZLE_DISPLAY_ORDER_LENGTH; puzzle++) {
    wakingPuzzleName[0] = '0' + puzzleDisplayOrder[puzzle];
    drawWakeStatus(puzzle, wakingPuzzleName);
  }
}



// Setup for performing Wake State activities
void transitionToWakeState() {

  // Initialize the status pixel and set initial controller state Wake
  setupControllerStatus();

  for (uint8_t puzzle=0; puzzle<PUZZLE_DISPLAY_ORDER_LENGTH; puzzle++) {
    puzzleWakeStatus[puzzleDisplayOrder[puzzle]] = WakeStates::Unknown;
  }
  currentPuzzle = 0;
  currentPuzzleID = puzzleDisplayOrder[currentPuzzle];
  commandSent = false;
  wakeTimeout = false;

  lcd.clear();
  lcd.setCursor(0,0);
  lcd.print(F("Phone Home Busy Box"));

  tft.fillScreen(BACKGROUND_COLOR);
  drawWakeStatus();

}

// Wake up all the Puzzles
void performWake() {
  bool next = false;
  if (puzzleDisplayOrder[currentPuzzle] == CONTROL_ID) {
    Serial.println(F("Skipping Controller"));
    puzzleWakeStatus[currentPuzzleID] = WakeStates::Awake;
    drawWakeStatus(currentPuzzle, ControllerShortName);
    next = true;
  }

  else if (!commandSent) {
    //Serial.print(F("Waking "));
    //Serial.println(puzzleDisplayOrder[currentPuzzle]);
    sendWake(currentPuzzleID);
    puzzleWakeStatus[currentPuzzleID] = WakeStates::Asked;
    commandSent = true;
    commandSentAt = millis();
    char wakingPuzzleName[] = "??";
    wakingPuzzleName[0] = '0' + currentPuzzleID;
    drawWakeStatus(currentPuzzle, wakingPuzzleName);
  }
  else {
    if (commandReady && command == COMMAND_ACK) {
      //Serial.print(F("ACK Received from "));
      //Serial.println(commandArgument);
      puzzleWakeStatus[currentPuzzleID] = WakeStates::Awake;
      //strncpy(puzzleShortNames[puzzleDisplayOrder[currentPuzzleID]], commandArgument, 11);
      //puzzleShortNames[currentPuzzle][9] = 0;
      puzzleNumberSize[currentPuzzleID] = (commandArgument[0] == 'A') ? 'A' : commandArgument[0] - '0';
      drawWakeStatus(currentPuzzle, &commandArgument[1]);

      // Move on to Next puzzle
      next = true;
      clearCommand();
    }
    else if ((millis() - commandSentAt) > TIMEOUT_MILLIS) {
      Serial.println(F("Timeout"));
      puzzleWakeStatus[puzzleDisplayOrder[currentPuzzle]] = WakeStates::Timedout;
      wakeTimeout = true;
      char wakingPuzzleName[] = "??";
      wakingPuzzleName[0] = '0' + currentPuzzleID;
      drawWakeStatus(currentPuzzle, wakingPuzzleName);
      next = true;
    }
  }

  if (next) {
      // Move on to Next puzzle
      currentPuzzle++;
      currentPuzzleID = puzzleDisplayOrder[currentPuzzle];
      commandSent = false;
  }

  if (currentPuzzle >= PUZZLE_DISPLAY_ORDER_LENGTH) {
    if (wakeTimeout) {
      // pause waiting for the screen to be touched
      lcd.setCursor(0,2);
      lcd.print(F("Tap Screen"));
      lcd.setCursor(0,3);
      lcd.print(F("to Continue"));
      while(!ts.touched()) {}
    }
    transitionToReadyState();
  }

}

void drawPuzzleDifficulty() {

  for (uint8_t difficulty=0; difficulty<DIFFCULTY_DISPLAY_LENGTH; difficulty++) {
    uint8_t row = 0;
    uint8_t col = difficulty % DIFFCULTY_DISPLAY_LENGTH;
    uint16_t startX = col*(DIFFICULTY_WIDTH+DIFFICULTY_PADDING) + DIFFICULTY_OFFSET_X;
    uint16_t startY = row*(DIFFICULTY_HEIGHT+DIFFICULTY_PADDING) + DIFFICULTY_OFFSET_Y;
//    int width = DIFFICULTY_WIDTH;
//    int height = DIFFICULTY_HEIGHT;

    // Draw Outline
    tft.fillRoundRect(startX, startY, DIFFICULTY_WIDTH, DIFFICULTY_HEIGHT, DIFFICULTY_RADIUS, difficlutyDisplayColors[difficulty]);


    // Draw Labels
    startX += (DIFFICULTY_WIDTH - (strlen(difficultyDisplayNames[difficulty]) * DIFFICULTY_TEXT_CHAR_WIDTH))/2;
    startY = (TFT_HEIGHT - DIFFICULTY_TEXT_CHAR_HEIGHT)/2;
    tft.setTextSize(DIFFICULTY_TEXT_SIZE);
    tft.setTextColor(DIFFICULTY_TEXT_COLOR);
    tft.setCursor(startX, startY);
    tft.print(difficultyDisplayNames[difficulty]);
  }

}


// Setup for performing Ready State activities
void transitionToReadyState() {
  setControllerState(ControllerStates::Ready);

  tft.fillScreen(BACKGROUND_COLOR);
  drawPuzzleDifficulty();

  printLCD(Select_Difficulty);   // Ask to select Difficulty

}

void performReady() {
  boolean istouched = ts.touched();
  if (istouched && !wasTouched) {
    TS_Point p = ts.getPoint();
    //Serial.print("Pressure = ");
    //Serial.print(p.z);
    //Serial.print(", x = ");
    //Serial.print(p.x);
    //Serial.print(", y = ");
    //Serial.print(p.y);
    //delay(30);
    //Serial.println();
    int yVal = map(p.x, TS_MINY, TS_MAXY, 0, TFT_HEIGHT);
    int xVal = map(p.y, TS_MINX, TS_MAXX, 0, TFT_WIDTH);
    //Serial.print(F("TFT X: "));
    //Serial.print(xVal);
    //Serial.print(F(" Y: "));
    //Serial.print(yVal);
    //Serial.println();
    difficulty = xVal/(DIFFICULTY_WIDTH+DIFFICULTY_PADDING);
    puzzleDifficulty = difficultyDisplayNames[difficulty][0];
    Serial.print(F("Difficulty = "));
    Serial.print(puzzleDifficulty);
    Serial.print(F("("));
    Serial.print(difficulty);
    Serial.println(F(")"));
    transitionToPlayingState();
  }
  wasTouched = istouched;
}


void transitionToPlayingState() {
  setControllerState(ControllerStates::Playing);

  // Setup the Target number
  targetNumberPos = rand() % difficultyPuzzleChoice[difficulty];
  nextNumberPosition = 0;
  // Copy the number over as is
  strncpy(randomPuzzleNumber, targetPuzzleNumbers[targetNumberPos], TARGET_NUMBER_LENGTH);
  randomPuzzleNumber[TARGET_NUMBER_LENGTH] = 0;

  // Copy the puzzle play order as is
  for (uint8_t p=0; p<PUZZLE_PLAY_LENGTH; p++) {
    puzzlePlayOrder[p] = defaultPlayOrder[p];
  }
  switch (puzzleDifficulty) {
    case DIFFICULTY_HARD:
      // randomize the digits
      for (uint8_t n=0; n<TARGET_NUMBER_LENGTH; n++) {
        uint8_t r = rand() % TARGET_NUMBER_LENGTH;
       char parkedChar = randomPuzzleNumber[n];
       randomPuzzleNumber[n] = randomPuzzleNumber[r];
       randomPuzzleNumber[r] = parkedChar;
      }

    case DIFFICULTY_MEDIUM:
      // randomize the play order - skipping the last (phone dialer)
      for (uint8_t p=0; p<PUZZLE_PLAY_LENGTH-1; p++) {
        uint8_t r = rand() % (PUZZLE_PLAY_LENGTH-1);
        uint8_t parkedNum = puzzlePlayOrder[p];
        puzzlePlayOrder[p] = puzzlePlayOrder[r];
        puzzlePlayOrder[r] = parkedNum;
      }

    default:
    case DIFFICULTY_EASY:
      break;
  }
  randomPuzzleNumber[TARGET_NUMBER_LENGTH] = 0;

  currentPuzzle = 0;
  currentPuzzleID = puzzlePlayOrder[currentPuzzle];
  //currentPuzzleLongName[0] = 0;

  commandSent = false;

  elapsedMinutes = 0;
  elapsedSeconds = 0;
  lastMillis = millis();
  showPlayFTF();
}
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
void loop()
{
  loopPJON();

  switch (controllerState) {
    case ControllerStates::Starting:
      performWake();
      break;
    case ControllerStates::Ready:
      performReady();
      break;
    case ControllerStates::Intialize:
      // This state is not used by the controller
      // It is only here for completeness
      break;
    case ControllerStates::Playing:
      performPlaying();
      break;
    case ControllerStates::Solved:
      if (ts.touched()) {
        transitionToWakeState();
      }
      break;
    default:
      Serial.print(F("Invalid State: "));
      Serial.println(controllerState);
      break;
  }
  if (commandReady) {
    if (command == COMMAND_WAKE) {
      // Wake could happen at any time - good for debugging
      transitionToWakeState();
    }
    else {
      // Unknown command or command not valid in current state
      Serial.print(F("Command '"));
      Serial.print(command);
      Serial.print(F("' "));
      if (commandArgument[0] != 0) {
        Serial.print(F("with args "));
        Serial.print(commandArgument);
      }
      Serial.print(F(" was not processed in state: "));
      Serial.println(puzzleStatesString[controllerState]);
    }
    clearCommand();
  }

}

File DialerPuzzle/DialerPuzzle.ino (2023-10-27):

/*
 * Phone Dialer
 *
 * Dial the right phone number in time
 *
 * First the Dialer must be put online by throwing the knife switch
 * then the number must be dialed correctly
 * Audio will be used to generate phone sounds
 */
#include <Arduino.h>
#include <Bounce2.h>
#include <PhoneHome_Definitions.h>
#include <PhoneHome_Command.h>
#include <PhoneHome_PuzzleState.h>
#include <SoftwareSerial.h>
#include <DFRobotDFPlayerMini.h>

// Puzzle definitions
const int   PuzzleId  = PHONE_ID;
const char* PuzzleShortName = "Phone";
const char* PuzzleLongtName = "Phone Home";
bool puzzleInitialized = false;
char puzzleDifficulty = DIFFICULTY_EASY;
#define MAX_NUMBER_LENGTH 'A'           // A for all


// Target Number
String targetNumber = "7950163";

// This pin indicates if the phone is online
const uint8_t onlinePin = 4;
// This pin indicates a number is being dialed
const uint8_t dialingPin = 5;
// This pin is the dialing pulses
const uint8_t pulsePin = 6; 

// Receive pin from DF Player
const uint8_t dfPlayerRxPin = 10;
// Transmit pin to DF Player
const uint8_t dfPlayerTxPin = 11;

// Maximum digits allowed in a phone number
const int maxPhoneNumberDigits = 7;
// Character representation of the number being dialed
char numberDialed[maxPhoneNumberDigits+1];
// The current digit dialed
int currentDigit;
// How many pulses have been detected for the current digit
int pulseCount;

// Define the States for the Dialer
typedef enum DialerStates {Idle, Online, Dialing, Connecting, Connected, Invalid} DialerStates;
// Character versions of State for Debug Printing
String dialerStatesString[] = {"Idle", "Online", "Dialing", "Connecting", "Connected", "Invalid"};
// Current state of the Dialer
DialerStates currentState = DialerStates::Idle;

// Debounce the Online transition
Bounce onlineSwitch = Bounce();
// Debounce the Dialing transition
Bounce dialingSwitch = Bounce();
// Debounce the Pulse transition
Bounce pulseSwitch = Bounce();

// Show the state of the switches
bool showSwitchState = true;

// DF Player settings
SoftwareSerial dfPlayerSerial(dfPlayerRxPin, dfPlayerTxPin); // RX, TX
DFRobotDFPlayerMini dfPlayer;

#define DFPLAYER_VOLUME 22
#define DIALTONE_FOLDER      1
#define RINGING_FOLDER       2
#define OFFHOOK_FOLDER       3
#define WRONG_NUMBER_FOLDER  4
#define DIALTONE_MP3         DIALTONE_FOLDER
#define RINGING_MP3          RINGING_FOLDER
#define WRONG_NUMBER_MP3     WRONG_NUMBER_FOLDER

// Instuctions
int instructionLine = 0;

//
// Instrutions for initializing the puzzle
//
// Limit to 20 chars  "                    "
const char Init_1[] = "Take Phone offline";
const char Init_2[] = "by lifting the";
const char Init_3[] = "Knife Switch";

const char *const Init[] =
{   
  Init_1,
  Init_2,
  Init_3
};

const int initLines = 3;

//
// Instructions for playing puzzle
//
// Limit to 20 chars  "                    "
const char Play_1[] = "Connect/Reset Phone";
const char Play_2[] = "using Knife Switch.";
const char Play_3[] = "Dial 7 digit number";
const char Play_4[] = "from other puzzles.";

const char *const Play[] =
{   
  Play_1,
  Play_2,
  Play_3,
  Play_4
};

const int playLines = 4;


void printDFPlayerStatus(uint8_t type, int value){
  switch (type) {
    case TimeOut:
      Serial.println(F("Time Out!"));
      break;
    case WrongStack:
      Serial.println(F("Stack Wrong!"));
      break;
    case DFPlayerCardInserted:
      Serial.println(F("Card Inserted!"));
      break;
    case DFPlayerCardRemoved:
      Serial.println(F("Card Removed!"));
      break;
    case DFPlayerCardOnline:
      Serial.println(F("Card Online!"));
      break;
    case DFPlayerUSBInserted:
      Serial.println("USB Inserted!");
      break;
    case DFPlayerUSBRemoved:
      Serial.println("USB Removed!");
      break;
    case DFPlayerPlayFinished:
      Serial.print(F("Number:"));
      Serial.print(value);
      Serial.println(F(" Play Finished!"));
      break;
    case DFPlayerError:
      Serial.print(F("DFPlayerError:"));
      switch (value) {
        case Busy:
          Serial.println(F("Card not found"));
          break;
        case Sleeping:
          Serial.println(F("Sleeping"));
          break;
        case SerialWrongStack:
          Serial.println(F("Get Wrong Stack"));
          break;
        case CheckSumNotMatch:
          Serial.println(F("Check Sum Not Match"));
          break;
        case FileIndexOut:
          Serial.println(F("File Index Out of Bound"));
          break;
        case FileMismatch:
          Serial.println(F("Cannot Find File"));
          break;
        case Advertise:
          Serial.println(F("In Advertise"));
          break;
        default:
          break;
      }
      break;
    default:
      break;
  }
  
}



// Turn on all visible lights and indicators for a little while as a test
void flashDisplays () {
  Serial.println(F("Flashing Displays"));
  // Turn on Lights and other indicators
  dfPlayer.playFolder(DIALTONE_FOLDER, DIALTONE_MP3);  //Play the Dialtone mp3
  delay(FLASH_DISPLAYS_DURATION);
  // Turn off Lights and other indicators
  dfPlayer.stop();
}


// Check if the puzzle is in a ready state
bool puzzleReady() {
  onlineSwitch.update();
  return onlineSwitch.read() == HIGH;
}



// PUZZLE STATE FUNCTIONS

// Perform actions when a Wake command is received
void performWake() {
  flashDisplays();
  sendAck(MAX_NUMBER_LENGTH, PuzzleShortName);
  setPuzzleState(PuzzleStates::Ready);
  clearCommand();

}

// Perform actions when a Start command is received
void performStart(String commandArgument) {
  puzzleInitialized = false;
  setPuzzleState(PuzzleStates::Intialize);
  clearCommand();

  puzzleDifficulty = (commandArgument.length() > 0) ? commandArgument[0] : DIFFICULTY_EASY;

  targetNumber = (commandArgument.length() > 1) ? commandArgument.substring(1) : targetNumber;
}

// Perform the Initialization steps including any randomizations
void performInitialize() {

  // Perform first time tasks such as randomization of drivers
  if (!puzzleInitialized) {
    puzzleInitialized = true;

    // Same for all Difficulties
//    switch (puzzleDifficulty) {
//      case DIFFICULTY_EASY:
//      case DIFFICULTY_MEDIUM:
//      case DIFFICULTY_HARD:
//      default:
//        break;
//    }

    if (!puzzleReady()) {
      dfPlayer.loopFolder(OFFHOOK_FOLDER);
      // Need to let Command know we will be in this state for a while
      sendInitialize(PuzzleLongtName);
      instructionLine = 0;
    }
  }

  // Wait until the puzzle has been reset by player
  if (puzzleReady()) {
    // Good to go - Let's play
    dfPlayer.stop();
    // Inform Command we are playing
    sendPlay(PuzzleLongtName);
    instructionLine = 0;
    setPuzzleState(PuzzleStates::Playing);
    
    // Ensure the dialed phone number is empty
    zeroNumberDialed();
    currentDigit = 0;
    pulseCount = 0;
    showSwitchState = true; // First time through show the switch state
    setState(DialerStates::Idle);
  }
}
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

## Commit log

2023-05-17 Added Connect Wires Puzzle
2023-09-01 Add Flip Bits from submodule
    [FlipBits.ino]
2023-09-05 added Dialer diagrams
    [Dialer Breadboard Schematic.fzz]
2023-09-05 added Slider diagrams
    [Slider Breadboard Schematic.fzz]
2023-09-05 added Command and Power connector
    [Dialer Breadboard Schematic.fzz, Slider Breadboard Schematic.fzz]
2023-09-05 clean up wires crossing
    [Dialer Breadboard Schematic.fzz]
2023-09-07 added Connect Wired diagrams
    [Connect Wires Breadboard Schematic.fzz]
2023-10-02 Added PJON support and flipped sliders
    [Slider.ino]
2023-10-02 Play Entertainer when solved
    [Controller.ino]
2023-10-02 Fixed playing loop for skipping not awake puzzles
    [Controller.ino]
2023-10-17 Added Instructions, Timer, and improved display
2023-10-21 moved instructions to module and reduced memory footprint
2023-10-21 removed array of puzzle short names
    [Controller.ino]
2023-10-27 puzzles send number of digits they can take; adjusted medium and hard difficulty; fixed bugs
    [Controller.ino, DialerPuzzle.ino, FlipBits.ino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]
2024-05-03 Added Slider Readme
    [Slider Breadboard Schematic.fzz]
2024-07-10 updated Assembly
2024-07-11 added README to describe Hook Me Up
    [Connect Wires Breadboard Schematic.fzz]
2024-07-11 added a little more detail to the soldering section
2024-07-12 added readme for Flip the Bits
    [FlipBits Breadboard Schematic.fzz]
2024-07-12 moved Fritzing files to fritzing directory
    [Connect Wires Breadboard Schematic.fzz, Slider Breadboard Schematic.fzz]
2024-07-14 renamed from ConnectWires to game name HookMeUp
    [HookMeUp Wires Schematic.fzz]
2024-07-14 renamed from Slider to game name SlideIntoHome
    [SlideIntoHome Breadboard Schematic.fzz]
2024-07-21 updated assembly with description of color mapping on final bottom view
2024-08-03 documented Spin Digit
    [SpinDigit Breadboard Schematic.fzz]
2024-08-03 made LED Bar Graph consistent and added info about the rotary switches light
2024-08-03 moved Dialer fritzing to the fritzing directory
    [Dialer Breadboard Schematic.fzz]
2024-09-01 Added README for Dialer Puzzle
    [Dialer Breadboard Schematic.fzz]
2024-09-03 Added Controller README
    [Controller Breadboard Schematic.fzz]
2024-09-10 Description for Power module
    [Power Breadboard Schematic.fzz]
2024-09-10 added link to power modules
2024-10-27 updated Power Overview with why certain parts were chosen
